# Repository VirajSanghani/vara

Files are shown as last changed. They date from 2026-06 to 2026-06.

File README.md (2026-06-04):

# VARA — a handheld perception instrument

> Point it at the world; slide on a cartridge, and it gains a new sense. The hero cartridge is
> a vision/macro lens — aim it at a plant, a part, a circuit, a label, and VARA identifies and
> explains it. The hero engineering component is the **dovetail rail connector** every cartridge
> shares, taken through a real, watchable optimization arc.

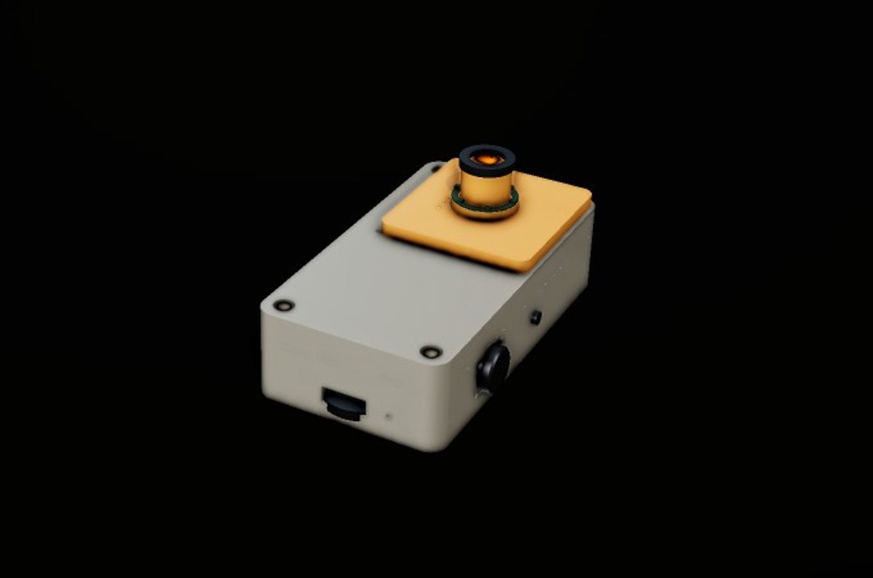
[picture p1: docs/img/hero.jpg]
VARA — assembled


*Interactive showcase (explode the device, watch the connector evolve, see the point-and-identify
loop): run `web/` locally — see [Run the showcase](#run-the-showcase-locally). Pronounced
**VAH-rah**, from Sanskrit वर — "boon, the chosen thing."*

---

## See it move

The whole assembly, every part flying from exploded to seated and back — on a loop. This is
rendered straight from the CAD: a single animated glTF (enclosure, the optimized dovetail
connector, M2.5 screws, and the representative internals) played in `<model-viewer>`.

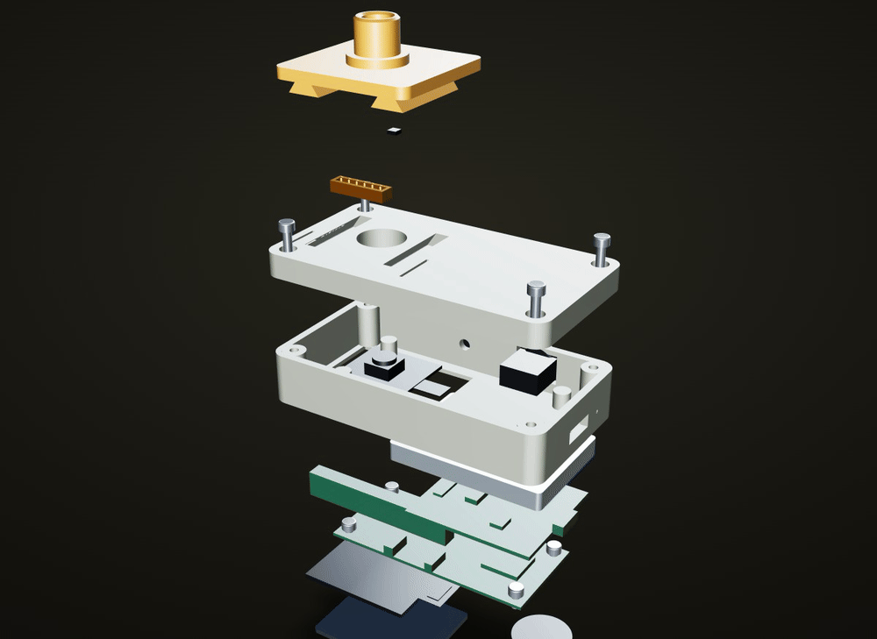
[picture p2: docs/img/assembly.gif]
VARA — the full device assembling, on a loop


Held open, the same geometry is an **annotated teardown** — every part on its own axis with a
leader label, each badged **DESIGNED** (geometry I engineered) or **REP** (a representative,
off-the-shelf stand-in I selected and modelled to size):

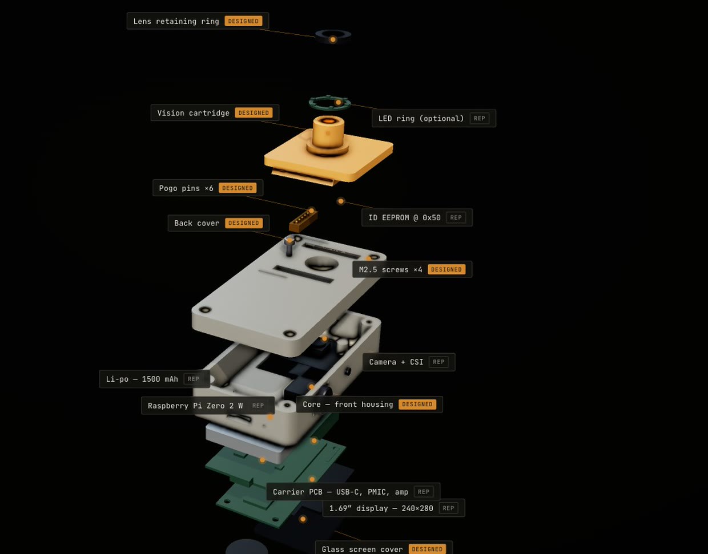
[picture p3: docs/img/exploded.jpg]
VARA — annotated exploded teardown


*Both come from the real Phase-6 part models with creased-normal shading and a studio HDR
environment. The standalone animation lives in [`web/assembly/`](web/assembly/); the annotated
teardown above is a frame from the fully interactive showcase in [`web/`](web/), where you can
drag the explode slider and tap any part for what it does **and why**.*

---

## Read this first — what VARA is, and isn't

VARA is **one complete, honest engineering pass** — hypothesis → printable enclosure + an
optimized connector → a representative integration → a working software prototype → an
interactive showcase → documentation — **not a manufactured product.**

- **No printer and no live hardware were in the loop.** Every fit, tolerance, force, and
  runtime here is **"validated-by-design," never "tested."** Where a number is analytical or an
  estimate, it says so.
- The **Raspberry Pi is the real brain**; the custom electronics are a **documented design**
  (schematic + netlist + BOM), **not a fabricated, routed, or electrically-verified board**.
- This honesty is the project's spine. For the robotics-lab role that seeded it, a credible
  end-to-end pass that's clear about its own boundaries is *more* useful than fake polish.

If you take one thing from this repo: **the record of decisions, dead ends, and tradeoffs is the
deliverable** — see [`BUILDLOG.md`](BUILDLOG.md).

---

## The story

**It starts with a capability probe, not a CAD model.** Before committing ambition, the tools
were tested ([`docs/tool-capabilities.md`](docs/tool-capabilities.md)): the FreeCAD MCP turned
out to be a dead stub, so all CAD runs on **build123d** (headless, parametric, diagnostics-first);
there's **no FEM available anywhere**, so stress is analytical and labelled as such; and **KiCad
was absent**, which set an honest ceiling for the electronics long before any schematic was drawn.

**The camera belongs in the core, not the cartridge.** A camera is a CSI-2 ribbon — far too fast
for a 6-pin pogo interface. Putting it in the core keeps the cartridge interface low-speed and
makes the hero cartridge *optics only*: a swappable macro lens over a fixed eye, like a microscope
objective. The payoff is a single constraint doing double duty — the cartridge lens must be
**coaxial** with the fixed camera, so the dovetail's **±0.28 mm** alignment budget governs the
*optical axis*, not just the electrical pads.

**The dovetail earned its place as the centerpiece** because its objectives genuinely fight:
locate precisely ↔ slide easily, lock firmly ↔ survive thousands of cycles, be stiff ↔ be
printable in PA12-CF. It was taken through **six problem-driven generations**
([`docs/dovetail-study.md`](docs/dovetail-study.md)), each fixing what the last exposed:

| Gen | What changed | Result |
|---:|---|---|
| **G1** | spec seed values | **catastrophic** — detent ε ≈ 13.5 %, ~1253 N to insert (it would shatter), alignment 0.40 mm |
| **G2** | a dedicated cantilever snap-finger | stress fixed in-plane, but fails the FDM interlayer case; alignment still off |
| **G3** | tighten clearance + declare a print-tolerance spec | alignment lands *exactly* on the 0.30 mm budget — kept as a marginal finding |
| **G4** | lower the detent depth | first **PASS** — but zero alignment margin |
| **G5** | thinner/longer finger, tighter fit | real margin — but the lock went soft (7.2 N) |
| **G6** | balance finger + detent + rail length | **resolved**: SF 5.1 / 2.56, **2.9 N** insert, **10.6 N** lock, **0.28 mm** alignment |

Beam theory understates the real stress at the finger root, so a **protected root fillet** carries
that load — and it's gated in code so a future refactor can't quietly shrink it. The marginal and
failing generations are kept, not hidden; they're how the part reasoned its way to a form.

**The electronics were designed honestly to a known ceiling.** `kicad-cli` validates and exports
but cannot place symbols, so the schematics were hand-authored as s-expressions and driven through
the CLI: openable `.kicad_sch`, an ERC-clean netlist (**0 unconnected pins**), and a BOM
([`docs/electronics.md`](docs/electronics.md)). The 6-pin contract — `V+ · GND · I²C SDA · I²C SCL
· CD# · INT` — maps exactly on both the core and the cartridge. **PCB routing was not pursued**
(the tool can't route); that limit is stated, not papered over.

**The prototype runs the real loop** ([`app/`](app/), [`docs/prototype.md`](docs/prototype.md)):
jog-press → camera capture → cloud vision identify → viewfinder + caption on the 1.69″ display →
speak. One detail is enforced *in code*: the shared V+ rail powers both the ID EEPROM and the LED
ring, and LED dimming PWMs that rail — so the firmware **must read the EEPROM ID before any PWM**.
`enable_power_pwm()` raises a `SequencingError` if it doesn't, and the demo proves the guard fires.
No Wi-Fi, no API key, or a timeout each produce a clean on-screen error — never a crash.

---

## Designed vs. representative — what I engineered, and what I selected

The line matters. **I engineered** the mechanical and interface design; I **selected** off-the-shelf
electronics and modelled them as dimensional stand-ins. This never rounds up to "designed the
electronics."

| **Designed by me** (geometry / interface / integration) | **Selected** (off-the-shelf, representative) |
|---|---|
| Dovetail connector — full optimization, male + female STLs | Raspberry Pi Zero 2 W (the compute / "brain") |
| Core enclosure (front housing + back cover), DfAM in PA12-CF | 1.69″ 240×280 ST7789 display module |
| Vision cartridge — lens barrel, LED-ring + EEPROM pockets, rails | Li-po cell, IP5306 PMIC, MAX98357A amp, USB-C |
| The 6-pin interface **contract** (pinout, EEPROM scheme, keep-outs) | Pi camera module + CSI ribbon |
| Fastener plan (M2.5 SHCS), heat-set bosses, print orientation | EC11 jog encoder, MEMS mic, speaker |
| The electronics **schematic / netlist / BOM** (a design) | — *(no routed PCB exists; not claimed)* |
| The Pi software pipeline + the read-before-PWM guard | — |

In the showcase teardown, every part carries a **DESIGNED** or **REPRESENTATIVE** badge for the
same reason.

---

## What it can do — and where it can go

VARA is a **platform**, not a single gadget. The thing that makes it one is the frozen interface
contract: a cartridge is anything that fits the dual-rail dovetail envelope and speaks the 6-pin
bus — `V+ (3V3 switched, ≤150 mA) · GND · I²C SDA · I²C SCL · CD# (detect) · INT`, with an
EEPROM ID at `0x50`. Design that contract once, and every future "sense" is just a new cartridge.

**What works today (the prototype loop, [`app/`](app/)).** Jog-press → the core camera captures →
a cloud vision model identifies → a viewfinder + caption render on the 1.69″ display → it speaks.
The core reads the cartridge's EEPROM ID on attach and can branch behaviour per cartridge. Every
failure mode (no Wi-Fi, no API key, a timeout) degrades to a clean on-screen message, never a
crash. This is **logic-validated with swappable stubs, not hardware-tested.**

**Designed-in extensibility (the contract already supports it).** Because the connector and bus
are frozen, these need *no change to the core* — only a new cartridge body + an I²C sensor:

| New "sense" | Representative sensor | Fits because |
|---|---|---|
| **Thermal / IR** | MLX90640 32×24 array | low-rate I²C, brings its own optics |
| **Air-quality / smell** | BME688 gas·VOC·T·RH·P | pure I²C, microwatts |
| **Macro / microscope** *(the hero, built)* | swappable lens over the core eye | exercises the ±0.28 mm optical-axis budget |

The honest edge case is **audio/ultrasonic**: raw streaming exceeds the low-speed 6-pin contract,
so that cartridge would need a small on-cartridge MCU to do DSP and report over I²C. That's not a
flaw — it's the contract telling you where its boundary is (see
[`docs/future-cartridges.md`](docs/future-cartridges.md); none of these are modelled).

**Where it could go next — concrete, unbuilt.** In rough order of "makes it real":

- **Close the hardware loop** — actually print the enclosure in PA12-CF, *measure* the dovetail
  fit and snap force against the analytical predictions, and **route + fabricate the PCB** (routing
  was explicitly not done; the design stops at an ERC-clean schematic/netlist/BOM).
- **Go offline / on-device** — swap the cloud vision call for a small local model on the Pi, so
  identification works with no network; keep the cloud path as an optional "deep" mode.
- **More senses** — any of the I²C cartridges above; a UV or polarised-light optic; a barcode/OCR
  reader; a depth or telephoto module (CSI-bandwidth senses live in the *core*, like the camera).
- **Smarter compute** — drop in a Pi 5 / CM4 / Jetson-class board behind the same enclosure and
  interface for heavier on-device perception, or add a follow-up voice-Q&A loop over each result.
- **Add a high-speed contract variant** — a superset connector for senses the 6-pin bus can't
  carry, without breaking the low-speed cartridges that already conform.

The spine still holds for all of it: this repo is **validated-by-design, not manufactured or
hardware-tested** — the value is a contract proven to generalise and a record of how it got there.

---

## Repo map

```
vara/
  BUILDLOG.md          phase-by-phase decision record (read this for the process)
  docs/                architecture · connector-spec · dovetail-study · mechanical ·
                       electronics · prototype · tool-capabilities · future-cartridges
  cad/                 build123d sources + ST/STEP/glTF  (connector/ core/ cartridge/ showcase/)
  electronics/         hand-authored KiCad schematics, CLI-exported netlist/BOM/PDF, ERC
  app/                 the Pi prototype (capture → vision API → display + speak); see app/README.md
  web/                 the Three.js exploded showcase (static, no build)
```

## Run the showcase locally

It's static files, no build step — just serve the folder (ES modules need http, not `file://`):

```bash
cd web && python3 serve.py 8000      # no-cache static server → http://localhost:8000
# or any static server: python3 -m http.server 8000
```

Three scenes: **Explode** (drag the slider; tap a marker for what each part does *and why*),
**Connector** (step/play the six generations with the real numbers), **Identify** (the
point-and-identify story with the real prototype frames). Drag to orbit; use the **view** presets.
Needs internet (three.js loads from the jsdelivr CDN).

There's also a **standalone auto-playing assembly animation** at **`web/assembly/`** — the full
device flying from exploded to seated, on a loop, built as an animated glTF and played in
`<model-viewer>` (a simpler, passive alternative to the interactive scene).

## Run the Pi app

See [`app/README.md`](app/README.md) for flashing a Zero 2 W and wiring. Off-device, the logic
path runs with stubs:

```bash
pip install pillow anthropic
python3 -m app.demo        # exercises init + a scan + every failure mode
```

**What's stubbed off-device:** camera, display, audio, encoder, cartridge I²C, and the vision API
are swappable stubs (each logs "STUB" at startup); the rendered display frames are real. On a Pi
with the libs + an `ANTHROPIC_API_KEY` in a gitignored `.env`, the real drivers take over. The app
is **logic-validated, not hardware-tested**.

---

## License

Mixed software + hardware, so the recommendation is a **dual license** — see [`LICENSE`](LICENSE):
**MIT** for the software (`app/`, `web/`, build scripts) and **CERN-OHL-S v2** (strongly
reciprocal) for the hardware (`cad/`, `electronics/`). MIT keeps the software trivially reusable;
CERN-OHL-S keeps hardware derivatives open. (A single permissive license is the alternative if
simplicity matters more — the tradeoff is laid out in `LICENSE`.)

## Built with

- **[build123d](https://github.com/gumyr/build123d)** 0.10 via the **forge-cad** pipeline — all parametric CAD, diagnostics, and glTF export.
- **[three.js](https://threejs.org/)** r160 (CDN-pinned) — the interactive showcase.
- **[KiCad](https://www.kicad.org/)** 10.0.3 (`kicad-cli`) — schematic validation + netlist/BOM/PDF export.
- **Raspberry Pi Zero 2 W** + the **Anthropic** vision API — the prototype brain and perception.

*A complete engineering pass, documented as an engineer would — decisions, tradeoffs, and dead ends.*

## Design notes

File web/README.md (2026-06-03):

# VARA showcase (web/)

The interactive exploded showcase — the wrapper that makes the whole build legible in ~60 s.
Static Three.js, **no build step**. It consumes the **real** project geometry and data:

- `assets/models/core.glb`, `cartridge.glb` — the Phase-3 printable parts (build123d → glTF).
- `assets/models/gen1…6.glb` — the Phase-2 dovetail evolution set.
- `assets/frames/*.png` — the Phase-5 prototype's real display renders.
- numbers in `src/data.js` come straight from `docs/dovetail-study.md` (analytical estimates).

## Three scenes
1. **Explode** — core ↔ cartridge separate; tappable markers give *what* each feature does
   **and why it's shaped that way** (rail span drove the form, the optical bore is coaxial,
   the finger-root fillet is functional, …).
2. **Connector** — step/play through the 6 generations, G1 (ε 13.5 %, 1253 N, FAIL) →
   G6 (SF 5.1, 2.9 N insert, 10.6 N retention, RESOLVED), numbers updating live.
3. **Identify** — the product story + the cartridge sliding on + the capture→identify→speak
   loop using the real Phase-5 frames.

## Run / deploy
It's plain static files — serve the folder over HTTP (ES modules need http, not `file://`):
```bash
cd web && python3 -m http.server 8000   # → http://localhost:8000
```
Deploy by uploading `web/` to any static host (GitHub Pages, Netlify, Cloudflare Pages, S3).
That URL is the single shareable link.

## Notes
- **Three.js r160 loads from the jsdelivr CDN** (pinned) via an import map — keeps the artifact
  light. For a fully offline/self-contained copy, vendor `three.module.js` + the four addons
  (`GLTFLoader`, `OrbitControls`, `CSS2DRenderer`, `RoomEnvironment`) and repoint the import map.
- **Perf:** meshes are already light (≤ ~95 KB each, no decimation needed); evolution GLBs and
  frames lazy-load on first entry to each scene; pixel ratio is capped (1.5× on mobile, 2× otherwise).
- **Graceful degradation:** a WebGL check shows a clean fallback message; layout reflows for mobile.
- **Honesty in the UI:** a persistent footer states the numbers are first-order analytical
  estimates — validated-by-design, not hardware-tested.

## Files
```
index.html        shell + import map + scene panels
src/styles.css    Quiet Utility theme (Fraunces + JetBrains Mono, stone/amber)
src/main.js       renderer, materials, the 3 scenes, lazy loading, camera moves
src/data.js       part callouts (what/why), gen metrics, story, honesty text
assets/           models/ (real glTF) · frames/ (real Phase-5 renders)
```

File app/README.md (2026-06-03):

# VARA prototype — run & flash

The functional pipeline: **jog-press → camera capture → cloud vision identify → viewfinder +
caption on the 1.69″ display → speak**. The brain is a real Raspberry Pi Zero 2 W; identify+
explain is a cloud API call (no on-device VLM — Phase 1). See `../docs/prototype.md` for what
runs vs. what's stubbed and the handled failure modes.

## Off-Pi logic demo (no hardware)
```bash
pip install pillow anthropic          # only these needed for the demo
python3 -m app.demo                   # exercises init + a scan + every failure mode
```
Renders display frames to `app/_out/` and a TTS transcript. **Logic-validated, not
hardware-tested** — camera/display/audio/cartridge/vision are stubs (logged at startup).
Sample frames are committed in `app/samples/`.

## Run on a real Raspberry Pi Zero 2 W
1. **Flash** Raspberry Pi OS (Bookworm, 64-bit Lite) with Raspberry Pi Imager; set Wi-Fi +
   SSH in the imager (Wi-Fi is required — the vision call needs network).
2. **Enable interfaces:** `sudo raspi-config` → enable **SPI** (display), **I2C** (cartridge
   EEPROM), **I2S** (audio), and the **camera**.
3. **Wire** per `../electronics/` (SPI display, I²S mic+amp, EC11 on GPIO5/6/16, USB-C PMIC,
   CSI camera, 6-pin pogo). Pin map = `../electronics/netlist.csv`.
4. **Install:**
   ```bash
   sudo apt install -y espeak-ng python3-picamera2
   pip install -r app/requirements.txt st7789 gpiozero smbus2
   cp .env.example .env && nano .env        # paste ANTHROPIC_API_KEY
   ```
5. **Run:** `python3 -m app.main`  (jog press = scan, long-press = shutdown).
   For boot-on-power, wrap in a `systemd` service.

Missing any Pi library → that subsystem auto-falls-back to its **stub** (logged), so the app
still starts. No `ANTHROPIC_API_KEY` → degraded mode showing a clean "No API key" screen.

## Layout
```
app/
  config.py      .env load + REAL/STUB selection (logged)
  state.py       pipeline states + typed vision errors
  vision.py      cloud client (RealVisionClient + StubVisionClient)
  pipeline.py    cartridge init (ID→PWM) + scan loop + degradation
  main.py        real-device entry           demo.py  off-Pi logic demo
  hal/           camera · display · audio · control · cartridge  (interface + real + stub)
```

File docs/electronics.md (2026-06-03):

# VARA — Electronics Design (Phase 4)

**Date:** 2026-06-03 · Artifacts: `electronics/netlist.csv`, `electronics/bom.csv`,
(stretch) `electronics/vara.kicad_*`. Tied to `connector-spec.md` **v0.2** (6-pin pogo).

> ## ⚠️ Honesty banner — read first
> **This is a DESIGN — schematic + footprints + BOM — NOT a DRC-clean, manufactured, or
> electrically-verified board.** No SPICE, no signal-integrity, no power-rail validation, no
> hardware. **No fake netlists:** every net in `netlist.csv` traces either to the frozen
> connector contract (the 6 pogo pins) or to a named component pin from `bom.csv`. Pin
> numbers for the Pi header are the physical 40-pin positions; verify against the chosen
> module before fab. Treat all of this as "validated-by-design," never tested.

---

## 1. Tooling ceiling (Phase 0 discipline, re-probed for Phase 4)
See the **Phase 4 addendum in `tool-capabilities.md`** for the empirical re-probe. Summary:
KiCad **10.0.3** installed (cask fetch + manual app extraction — full cask needs sudo);
`kicad-cli` **validates/exports but cannot place symbols**, so schematics are hand-authored
as `.kicad_sch` then driven through the CLI.

**Both floor and stretch are delivered:**
- **Floor:** `electronics/netlist.csv`, `electronics/bom.csv`, block diagram (§2), contract
  mapping (§3).
- **Stretch (verified working):** openable, ERC-checked `vara_core.kicad_sch` +
  `vara_cartridge.kicad_sch` (generated by `gen_kicad_sch.py`), with CLI-exported
  **netlist** (`*.net`), **BOM** (`*.bom.csv`), and **PDF** (`*.pdf`).
  - **Connectivity proven by the exported netlist:** core = **29 nets, 0 unconnected pins**;
    cartridge = **6 nets, 0 unconnected pins**. The 6 contract nets map exactly (§3).
  - **ERC:** no electrical errors; only cosmetic warnings remain — `lib_symbol_issues` /
    `footprint_link_issues` (the custom symbol lib and footprints aren't registered in a
    project library table; symbols are embedded so the files open, footprints are referenced
    by name for the BOM). No dangling labels, no unconnected pins.
- **PCB layout NOT pursued:** `kicad-cli pcb` cannot place/route; per the brief, routing is
  optional dessert. We stop at schematic + netlist + BOM + PDF depth.

---

## 2. System block diagram

```mermaid
graph LR
  USBC[USB-C J1] -->|VBUS 5V| PMIC[IP5306 PMIC U2]
  BATT[Li-po 1500mAh BT1] <-->|charge / boost| PMIC
  PMIC -->|+5V| PI[Pi Zero 2 W A1]
  PMIC -->|+5V| AMP[MAX98357A U4]
  PMIC -->|+5V| LDO[AP2112 3V3 U6]
  LDO -->|+3V3_SYS| DISP[1.69 ST7789 DS1]
  LDO -->|+3V3_SYS| MIC[SPH0645 MK1]
  LDO -->|+3V3_SYS| LSW[Load switch U5]
  PI -->|SPI0 + DC/RST/BLK| DISP
  PI <-->|I2S BCLK/LRCLK| MIC
  PI -->|I2S DOUT| AMP
  MIC -->|I2S DIN| PI
  AMP -->|BTL| SPK[Speaker LS1]
  PI <-->|A/B/SW| ENC[Encoder SW1]
  ENC -->|long-press| PMIC
  PI -->|CSI-2 FFC| CAM[Camera CAM1]
  PI -->|GPIO26 EN/PWM| LSW
  LSW -->|V+ switched 3V3| J2
  PI <-->|I2C1 SDA/SCL| J2
  PI <-->|CD#, INT| J2
  J2[[6-pin pogo J2]] ===|pogo| PADS[Cartridge pads]
  PADS --> EE[EEPROM 0x50 U3]
  PADS --> LED[LED ring D1-6]
  PADS --> SHUT[Shutter SW2 -> INT]
```

---

## 3. The cartridge interface — netlist tied EXACTLY to `connector-spec.md` v0.2
The contract is 6 pins. Every one maps to a real net on both sides:

| Pin | Contract net | CORE side (net / node) | CARTRIDGE side (net / node) |
|----:|---|---|---|
| 1 | **V+ (3V3 switched)** | `V+_SW` ← U5.VOUT (load switch, ≤150 mA, EN=GPIO26) | `CV+` → U3.VCC + LED-ring anodes |
| 2 | **GND** | `GND` (J2.2) | `CGND` → U3.GND/A0/A1/A2/WP, LED return, SW2 |
| 3 | **I²C SDA** | `I2C_SDA` ← GPIO2, pull-up R1 4.7k→3V3 | `CSDA` → U3.SDA |
| 4 | **I²C SCL** | `I2C_SCL` ← GPIO3, pull-up R2 4.7k→3V3 | `CSCL` → U3.SCL |
| 5 | **CD# (detect)** | `CART_CD` ← GPIO23, pull-up R3 10k→3V3 | `CCD` = **hard-tied to GND** (presence) |
| 6 | **INT** | `CART_INT` ← GPIO12, pull-up R4 10k→3V3 | `CINT` ← SW2 shutter (to GND when pressed) |

**Mate/power sequence (firmware, per connector-spec §4.2):** CD# falls (seated) → Pi enables
`CART_VEN` (V+ load switch on) → settle → read EEPROM @0x50 → configure pipeline → arm INT.

---

## 4. Subsystem notes & deliberate design decisions
- **Power chain:** IP5306 does charge + 5 V boost + power-path + button + fuel gauge in one
  chip (board-area win). Pi runs from +5 V and uses its own internal regulators. A separate
  **AP2112 3V3 LDO (U6)** derives `+3V3_SYS` for peripherals **and** the switched cartridge
  rail — deliberately **not** tapping the Pi's weak 3V3 header pin, which couldn't source the
  cartridge's ≤150 mA.
- **Switched cartridge rail (U5):** a current-limited load switch gates V+ so (a) a fault on a
  cartridge can't brown out the core, and (b) V+ is off until the core has identified the
  cartridge. `R5` 100k holds it off at boot.
- **LED-ring dimming without a 7th pin:** there is no dedicated PWM line in the 6-pin
  contract, so the **core PWMs the V+ load switch (GPIO26)** to dim the ring. The EEPROM is
  read **once at insertion while V+ is steady**, *before* any PWM — so power-cycling the rail
  for dimming doesn't disturb ID. Documented tradeoff, not a hidden hack.
- **Audio:** I²S mic (SPH0645) and amp (MAX98357A) share BCLK/LRCLK; mic on PCM_DIN, amp on
  PCM_DOUT — standard full-duplex I²S.
- **Camera:** Pi camera connects by the **CSI-2 FFC ribbon to the Pi's camera port (J3),
  NOT through the pogo pins** — CSI is far too high-bandwidth for the 6-pin low-speed contract
  (this is *why* the camera lives in the core; see architecture.md §2).
- **Single control:** the EC11 encoder's A/B/SW go to the Pi for UI.

## 5. Known integration risks (named, per honesty rules)
1. **Shared button (`ENC_SW` = `PWR_KEY`):** the encoder push drives both a Pi GPIO (UI) and
   the IP5306 KEY (power). IP5306's long-press/double-click power behaviour can collide with
   UI gestures. **Mitigation option** if it proves annoying: a separate dedicated power
   tactile on KEY, freeing the encoder for UI only. Flagged for bench resolution.
2. **Pi header pin numbers** are the physical positions for a standard 40-pin Zero 2 W; the
   chosen GPIO↔function map (SPI0, I²C1, I²S, the GPIO assignments) must be confirmed against
   the device-tree overlay before fab.
3. **Current budget:** the ≤150 mA cartridge rail assumes a modest LED ring (6× ~20 mA with
   R6 limiting). A brighter ring needs a rethink of U5 / rail sizing.
4. **No power-integrity / EMC / thermal analysis** has been done.

## 6. What is explicitly NOT claimed
No DRC pass, no routed-and-poured copper claimed as verified, no impedance control, no
manufactured board, no electrical bring-up. The deliverable is a **coherent, contract-tied
design** an engineer could take to layout — and the stretch artifacts (if the probe allows)
are an **openable KiCad project**, still a design, not a verified board.

## 7. Outputs
**Floor:**
- `electronics/netlist.csv` — every net, every node, tied to the connector contract or a BOM pin.
- `electronics/bom.csv` — full BOM with part numbers, packages + subsystems.

**Stretch (openable KiCad project + CLI exports):**
- `electronics/vara_core.kicad_sch`, `electronics/vara_cartridge.kicad_sch` — hand-authored,
  ERC-clean (cosmetic warnings only). Open in KiCad 10.
- `electronics/gen_kicad_sch.py` — the generator (single source: components + per-pin nets).
- `electronics/vara_core.net`, `vara_cartridge.net` — CLI-exported netlists (connectivity proof).
- `electronics/vara_core.bom.csv`, `vara_cartridge.bom.csv` — CLI-exported BOMs.
- `electronics/vara_core.pdf`, `vara_cartridge.pdf` — rendered schematics.
- `electronics/*.erc.rpt` — ERC reports. `electronics/*.kicad_pro` — project files.

> Reproduce: `python3 electronics/gen_kicad_sch.py` then
> `kicad-cli sch {erc,export netlist,export bom,export pdf} electronics/vara_core.kicad_sch`.

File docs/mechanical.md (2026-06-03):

# VARA — Mechanical Design & Design-for-AM (Phase 3)

**Date:** 2026-06-03 · Parts: **core body** + **hero vision cartridge**, both consuming the
**resolved Gen-6 connector geometry** (`connector-spec.md` v0.2) via `dovetail_lib`
primitives — the `[STUDY]` geometry was **not re-opened**. Source:
`cad/core/core_body.py`, `cad/cartridge/vision_cartridge.py`, `cad/vara_assembly.py`.

> **Honesty banner:** No printer is in the loop — every fit/orientation is
> **"validated-by-design, print-ready," never tested.** Material is **PA12-CF** (FDM).
> Internal packaging (Pi, battery, PMIC) is dimensionally representative, not a routed
> layout. The core is modeled as a **sealed unibody** for a clean watertight single-STL
> deliverable; the production part splits on a rear parting line (see §6).

---

## 1. What was built (and the gate results)

| Part | bbox (mm) | mass (PA12-CF) | solids | watertight | gates |
|---|---|---|---|---|---|
| Core body | 44 × 64 × 20 | 21.9 g | 1 | **yes** | **5/5** |
| Vision cartridge | 26 × 35.6 × 19 | 5.9 g | 1 | **yes** | **5/5** |
| Assembly (semi-exploded) | 44 × 64 × 43 | — | 2 | yes | **0 interferences** |

**Geometry gates run (forge `REQUIREMENTS`, on the real solids):**
- Core: valid+watertight · optical bore Ø13 clear path · pad strip flat (nothing past the
  mating plane) · rail socket actually formed · **protected finger-root fillet ≥ 0.5 mm**.
- Cartridge: valid · barrel bore (optical path) clear end-to-end · pad strip exposed below
  the mating plane · within 32×36×26 envelope · rails+barrel **fused to one solid**.

**Device proportions — honest consequence of the connector.** The rail span (35.6 mm in Y)
plus the 1.69″ display set the core at 44 W × 64 H × 20 T mm: a chunky, grippable instrument,
not a thin phone. That thickness/height is *driven by the frozen connector geometry* and the
need to seat the camera coaxially behind the cartridge — stated plainly rather than fought.

---

## 2. Core body — feature inventory
Display: 1.69″ 240×280 bezel recess (module 30.4×36.6, +0.4 clearance) with a through window
to the **28.0 × 32.6 mm active area** (viewfinder + caption split is software on one panel).
Back: integrated **female rail socket** (Gen-6, with the snap-finger slots + detents) and the
**Ø14 optical bore** coaxial with the cartridge barrel, behind it a camera mount pocket.
Sides/edges: **USB-C** cutout (bottom), **jog-encoder** aperture (right edge), **I²S mic**
port (bottom), **speaker grille** (3×3, front lower). Internal: sealed electronics cavity +
**4× M2.5 heat-set bosses** on the Pi Zero 2 W hole pattern (58 × 23 mm).

## 3. Vision cartridge — feature inventory
**Male rails** (Gen-6, consumed as-is, with seating dimples) → backing plate (3 mm) →
**macro-lens barrel** coaxial on the optical axis (Ø12 outer, **Ø8 bore = optical path**,
12 mm tall). **LED-ring recess** (Ø16/Ø12.5, 2 mm) around the barrel base facing the subject.
**EEPROM-ID pocket** (5×4×1.6 mm) on the underside near the pad strip. **6 flat pogo-pad
seats** (Ø2.0, 2.54 mm pitch, 0.3 mm recess) on the underside at X=6. Optical coaxiality of
the barrel is governed by the connector's **±0.28 mm** alignment budget.

---

## 4. Design-for-AM — per part

### Print orientation (the real tension, resolved per part)
There is **no single orientation optimal for every face**; each part is oriented for *its*
most critical faces, and the connector's alignment margin (0.28 < 0.30 mm) + the finger-root
fillet absorb the residual.

- **Core body → front-face-down.** Screen face flat on the bed (best cosmetic face); the
  back socket + bosses build upward. Two payoffs: (1) the female groove flanks sit at ~35°
  from vertical — **within the FDM ~45° self-support limit, no support in the sliding zone**;
  (2) layers stack along the device thickness (conn-Z), so the **snap finger flexes
  *in-plane*** → the **in-plane SF_yield ≈ 5.1 applies, not the interlayer case** (better than
  the Phase-2 worst-case assumption). Bosses' heat-set bores open upward (toward the print
  top), clean to ream.
- **Vision cartridge → rail-axis (X) vertical** (stand on the +X mouth end), per the Phase-2
  connector resolution. Rail flanks become near-vertical walls → **support-free sliding
  faces** (the alignment-critical surfaces win). Trade-offs, stated: the **barrel bore prints
  horizontally** (top crown slightly rough → **ream the Ø8 bore**, standard for an optical
  barrel); the **pad face prints vertical** → the flat gold pads are an adhered contact strip
  that seats into the 0.3 mm recess, so layer texture under them is non-critical.
  *(Rejected alternative: rail-floor-down — leaves a 26 mm unsupported plate-underside bridge
  across the central pad/optical channel, which would need support exactly on functional
  faces. Rejected.)*

### Wall thickness, clearances, supports, fasteners

| Item | Core | Cartridge |
|---|---|---|
| Wall thickness | 2.4 mm side / **3.0 mm front (screen)** (≈6–7 perimeters @0.4 mm) | 3.0 mm plate / **2.0 mm barrel** |
| Connector walls | female `wall_thk` 2.4, finger 1.1 (from study, unchanged) | rails per study |
| Support on functional faces | **none** (front-down → flanks self-support; finger in-plane) | **none on flanks** (rail-vertical); bore reamed |
| Fasteners / heat-set | **4× M2.5 heat-set** (Pi mount); melt bore Ø3.4 (Ø2.2 pilot shown) + rear-cover corner inserts (production) | **none** — snap-fit retention; LED ring / EEPROM / lens retained by pockets + adhesive |

### Tolerance call-outs
| Feature | Nominal | Tolerance / clearance |
|---|---|---|
| Dovetail flank fit | `flank_clearance` 0.13 mm | **per-part print tol ≤ ±0.075 mm** (calibrated printer) — required to hold ±0.30 mm budget (study §4) |
| Display module pocket | 30.4 × 36.6 mm | +0.4 mm |
| Optical bore | Ø14 (lens Ø12) | +0.0/−0.0 keep-out; lens clear aperture ≤ Ø12 |
| Pad pattern | 2.54 mm pitch, Ø2.0 | recess 0.3 mm; pads = adhered contact strip |
| USB-C cutout | 9.2 × 3.6 mm | +0.4 mm over connector body |
| Heat-set boss bore | Ø3.4 (M2.5) | per insert datasheet |

---

## 5. Keep-outs — validated by gate (not by eye)
- **Optical bore:** a Ø13 test cylinder through the core back is empty (< 5 mm³); the
  cartridge barrel **bore** is open end-to-end — the optical path is clear and coaxial. ✔
- **Pad strip:** nothing on either part protrudes past the mating plane into the X=6 pad
  footprint → pads stay flat for pogo contact. ✔
- **Central channel:** rails are outboard at Y=±13 (inner edge ≥ 7.0 mm by the connector
  gate), so pads (Y±6.35) and the Ø14 bore stay clear. ✔
- **Envelope:** cartridge 26×35.6×19 ≤ 32×36×26. ✔ (Y=35.6 is tight against the 36 mm limit
  — flagged; any future wider rail would breach it.)

## 6. Production note (why the core is a sealed unibody here)
A printed enclosure is two shells. The single watertight STL seals the electronics cavity
for a clean manifold deliverable; the **production core splits on a rear parting line** into
the front housing (shown) + a back cover, joined at the **4× M2.5 heat-set bosses** (on the
real Pi hole pattern). The cavity dimensions and boss pattern are the real internal layout;
only the closing face is sealed in this STL. The cartridge needs no such split (snap-fit).

## 7. Protected feature — finger-root fillet
The detent **finger-root fillet (0.6 mm)** is a **functional** feature: the straight-beam
stress model (study §2) understates the real stress concentration at the finger root, so the
fillet is what keeps the actual peak stress in check. It is gated (`finger_root_fillet ≥ 0.5`)
and **must not be reduced for packaging convenience**, per the Phase-3 brief.

## 8. Outputs & honest limitations
**Outputs:** `cad/core/core_body_v1.{stl,step}`, `cad/cartridge/vision_cartridge_v1.{stl,step}`,
`cad/vara_assembly_v1.glb`, per-part diagnostics in `cad/*/out/`.
**Limitations:** (1) internal packaging is representative, not routed — Pi/battery/PMIC fit is
asserted by envelope, not by a populated layout; (2) the sealed-unibody core defers the real
parting-line/cover detailing; (3) no fit, insertion, or drop behaviour is measured —
validated-by-design only.

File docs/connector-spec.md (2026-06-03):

# VARA Cartridge Interface — CONTRACT SPEC v0.2

**Date:** 2026-06-03 · **Status:** contract frozen for Phase 2/3; dovetail *profile* is a
Phase-2 study variable (clearly tagged below). **This document is the single source of
truth.** Every core and cartridge part references it. Change a value here → propagate
everywhere downstream (architecture, CAD, electronics). Bump the version on any change.

> Two kinds of numbers live here. **[CONTRACT]** = frozen; any cartridge ever built must
> conform, and the core mates to it. **[STUDY]** = the dovetail cross-section geometry being
> optimized in Phase 2; the current best always lives in `cad/connector/`. The contract is
> stable even while the profile evolves — that separation is deliberate.

---

## 1. Coordinate datum & reference frame [CONTRACT]

A single right-handed frame governs both halves. The **female** rail is in the **core**;
the **male** rail is on the **cartridge**.

```
            +Z  (out of core mating face; OPTICAL AXIS ∥ +Z; cartridge sits above)
             │           camera (in core) looks out +Z through cartridge barrel
             │
             │     ┌───────────── cartridge envelope ──────────────┐
             │     │   ◎ optical axis @ (Xopt,0)   ⦿ LED ring      │
             O─────┼────●●●●●● pad array @ (Xpad, Y)────────────────┼──▶ +X
          (datum   │                                                │   (removal dir;
           origin) └────────────────────────────────────────────────┘   insertion = −X)
             │      ◀── slides −X to seat against stop at X=0 ──
            +Y (lateral, into page complete RH frame)
```

- **Origin O** = center of the **positive-stop face**, on the rail axis, at the mating
  base plane. All features are dimensioned from O.
- **+X** = cartridge **removal** direction. Insertion travels **−X** until the male rail's
  seat face contacts the stop at **X = 0** (hard positive stop — cartridge cannot
  over-insert).
- **+Z** = normal to the core mating base plane, pointing toward the cartridge. The core
  camera looks out **+Z**; the cartridge lens barrel is coaxial above it.
- **+Y** = lateral, completing the right-hand frame.

---

## 2. Envelope [CONTRACT]

| Item | Value | Note |
|---|---|---|
| Max cartridge bounding box (W×L×H = Y×X×Z) | **36 × 32 × 26 mm** | hard ceiling; hero cartridge sits inside this |
| Mating base plane | Z = 0 | shared face between core and cartridge |
| Insertion direction | −X | seats against stop at X=0 |
| Rail nominal length (along X) | **24 mm** [STUDY] | bearing length; affects angular stiffness |

---

## 3. Pad array & optical axis (the alignment-critical features) [CONTRACT]

Pogo pins live in the **core** (protrude +Z); flat gold pads on the **cartridge** (on the
Z=0 plane, facing −Z toward the core).

| Feature | Location (from O) | Spec |
|---|---|---|
| Pad array center | X = **+6.0 mm**, Y = 0, Z = 0 | engages only near full seat |
| Pad pitch / count | **2.54 mm × 6** | pins along Y; outer pads at Y = ±6.35 mm |
| Pad size | **Ø2.0 mm gold** | ≥ pogo crown + 2×(0.3 mm budget) + margin |
| Pogo working compression | **0.5 mm** | sets the alignment budget below |
| **Optical axis** | X = **+15.0 mm**, Y = 0, along +Z | core camera ↔ cartridge barrel, coaxial |
| Optical clear bore (keep-out) | **Ø14 mm** about the optical axis, full Z | no structure intrudes (lens clear aperture ~Ø12 + margin) |
| Pad keep-out | pad rect + 1.0 mm margin, +Z to pogo housing | no ribs/walls in the contact volume |

### 3.1 Alignment budget [CONTRACT] — the number the dovetail must hold
The pogo compression (0.5 mm) and pad oversize give an absorbable misalignment of
**±0.3 mm** at the **pad plane** *and* at the **optical axis**, in Y and X.

This budget is **lateral + angular combined**. Angular slop is the dominant risk because
the optical axis (X=+15) is **9 mm forward of the pad centroid (X=+6)**, so rail tilt is
amplified by lever arm:

```
   error_at_optical_axis ≈ lateral_play + θ · (distance from rail-bearing centroid)
   require: error_at_optical_axis ≤ 0.3 mm  AND  error_at_pads ≤ 0.3 mm
```

→ **Phase-2 acceptance:** the chosen `flank_clearance` + rail bearing length must keep
both the pad-plane and optical-axis error ≤ 0.3 mm under worst-case clearance + a stated
print-tolerance allowance. This is the dovetail study's primary quantitative gate.

---

## 4. Electrical pinout — FINAL [CONTRACT]

Pin order along Y, from −Y outer pad (pin 1) to +Y outer pad (pin 6):

| Pin | Net | Direction / level | Notes |
|----:|-----|---|---|
| 1 | **V+ (3V3, switched)** | core→cart | Core-side **load switch + current limit, ≤150 mA budget**. Enabled by firmware *after* CD# asserts. Single logic+LED rail keeps the interface to 6 pins. |
| 2 | **GND** | — | Reference. (Provision: a longer GND pogo could make-first for hot-plug safety; design-time option, not testable without hardware.) |
| 3 | **I²C SDA** | bi | Pull-up **on core**. EEPROM + any future cartridge I²C sensor. |
| 4 | **I²C SCL** | core→cart | Pull-up **on core**. 100/400 kHz. |
| 5 | **CD# (cartridge-detect)** | cart→core | Cartridge **ties to GND**; core pulls up. Falling edge = seated → core enables V+ → reads EEPROM. Replaces the seed's resistor/1-Wire ID (Zero 2 W has no ADC, so a resistor divider would need an extra ADC chip — rejected). |
| 6 | **INT** | cart→core | Active-low, core pull-up. Cartridge interrupt (e.g. shutter button, sensor data-ready). |

### 4.1 Cartridge ID — EEPROM scheme [CONTRACT]
- I²C EEPROM (24AA02-class), fixed address **0x50**.
- Layout (starting): `magic(2) | cartridge_type(1) | hw_rev(1) | serial(4) | name[16] |
  calibration/params(rest)`. The core auto-detects which cartridge is mounted and adapts
  the UI/pipeline.
- Cheapest possible cartridge still carries this EEPROM (~$0.10) — cleaner and more
  capable than a resistor code, and it reuses pins 3/4 (no extra pin).

### 4.2 Mate/power sequence (firmware, not mechanical staggering)
Pads are coplanar and pogos equal-length → all contacts close together at full seat.
Sequencing is handled in firmware: detect **CD# low** → enable **V+ load switch** →
settle → read **EEPROM @0x50** → configure pipeline → arm **INT**. This avoids needing
mechanically staggered pin lengths (which we can't validate without hardware).

---

## 5. Dovetail profile — Phase-2 STUDY SEED [STUDY]

These define the *cross-section* being optimized. **Not** part of the frozen contract —
the current best geometry always lives in `cad/connector/` and feeds Part IV's study.
**Resolved in Phase 2 — see [`dovetail-study.md`](dovetail-study.md) for the 6-generation
derivation.** Configuration: **dual rails at Y = ±13 mm** flanking the central pad/optical
channel (a single central rail would collide with the pads + optical bore).

| Param | Seed | **Resolved (Gen 6)** | Meaning |
|---|---|---|---|
| `dovetail_angle` | 55° | **55°** | Flank angle from base plane (Z=0). 90° = vertical; <90° = undercut. 55° ⇒ 35°-from-vertical flanks — self-supporting when printed rail-axis-vertical (see §6). |
| `flank_clearance` | 0.20 mm | **0.13 mm** | per-side gap. Tightened to hold the ±0.3 mm budget with margin (E_align = 0.28 mm). |
| `detent_depth` | 0.6 mm | **0.50 mm** | snap engagement; balances retention (~10.6 N) vs. finger strain. |
| `rail_length` | 24 mm | **26 mm** | bearing length; keeps pads (X=6) & optical (X=15) well inside the span. |
| `wall_thk` | 2.4 mm | **2.4 mm** | female wall (≈6 perimeters @0.4 mm nozzle). |
| `lead_in_chamfer` | 1.0 mm | **1.2 mm** | +X mouth lead-in. |
| detent | X ≈ +2.5 mm | **cantilever finger 13×1.1 mm, one per rail** | Gen 1's wall-flex detent over-strained ~5×; replaced by dedicated snap fingers. |
| (print req) | — | **rail-axis-vertical; per-part tol ≤ ±0.075 mm** | required to meet alignment + keep flanks support-free. |

**Resolved performance (analytical, validated-by-design — NOT tested):** alignment
**0.28 mm ≤ 0.30**; detent **SF_yield 5.1 / SF_interlayer 2.56**; insertion **~2.9 N**,
retention **~10.6 N**; all geometry gates 6/6, watertight.

**Objectives in tension (per plan §4.2):** stiffness↔printability ·
retention force↔insertion ease · tight fit (alignment)↔wear life · wall thickness↔size.

---

## 6. Material & print intent [CONTRACT-level intent; details Phase 3]

- **Material:** PA12-CF, FDM. No printer in the loop → all fits are
  **"validated-by-design, print-ready," never tested.**
- **The core printability↔strength tension (to resolve in Phase 2):**
  - *Rail axis vertical (X ∥ Z-build):* sliding flank faces become near-vertical walls →
    clean surfaces, **no support on functional faces**. But layer lines run ⟂ to insertion
    and the **detent cantilever loads across layers** (weak interlayer adhesion in CF).
  - *Flat on bed (X horizontal):* strong, isotropic-ish detent; but the undercut flanks
    (35° overhang at 55°) become **overhangs needing support → wrecks the sliding faces.**
  - Phase 2 resolves this with geometry (e.g. raising `dovetail_angle` toward printable
    overhang limits) + orientation, logged as generations.

---

## 7. Keep-out summary (for body integration, Phase 3)

| Zone | Keep-out |
|---|---|
| Optical bore | Ø14 mm cylinder about (X=+15, Y=0), full Z, both halves |
| Pad/pogo volume | pad rect +1 mm margin, +Z to pogo housing height |
| Detent travel | clear path for the male rail X = 0 → +24 mm during insertion |
| LED ring | annulus around optical bore, within cartridge envelope; powered from V+ (≤150 mA) |

---

## Change log
- **v0.2** (2026-06-03): Phase 2 resolved the [STUDY] dovetail profile (§5) — dual rails,
  cantilever snap fingers, c=0.13, rail_length=26, etc. **[CONTRACT] sections unchanged.**
  See `dovetail-study.md`.
- **v0.1** (2026-06-03): initial contract. Camera in core; optics-only hero cartridge;
  6-pin pogo (V+/GND/SDA/SCL/CD#/INT); EEPROM ID @0x50; ±0.3 mm alignment budget serving
  pads *and* optical axis; dovetail profile seeded for Phase 2.

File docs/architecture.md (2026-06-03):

# VARA — System Architecture (Phase 1)

**Date:** 2026-06-03 · **Status:** subsystem choices locked for Phase 2/3 entry.
This document fixes the *system* decisions. The *interface contract* (envelope, datum,
pinout, keep-outs) lives in [`connector-spec.md`](connector-spec.md) — the single source
of truth every part references.

> Honesty note: every current-draw, runtime, and fit number here is a **documented
> estimate** marked *(est.)* or *(guess)*. Nothing is bench-measured — we have no
> hardware or printer in the loop. No fit is "tested," only "validated-by-design."

---

## 1. Subsystem decisions (locked)

| Subsystem | Decision | Key reasoning / tradeoff |
|---|---|---|
| **Compute** | **Raspberry Pi Zero 2 W** | Smallest Pi with WiFi + enough OS to drive camera/SPI/audio. On-device VLM inference is impossible on *any* Pi (see §3), so compute choice is about UX smoothness, not inference — which removes the headroom argument for Pi 4/5 and favors size. |
| **Display** | **1.69" IPS, 240×280, ST7789V-class, SPI** | Taller-than-square aspect splits naturally into **camera viewfinder (top) + result/caption strip (bottom)** — the point-and-identify UX. 1.54" 240×240 kept as drop-in fallback if module sourcing/space forces it. Front-face geometry anchors to this active area (§ connector-spec keep-outs). |
| **Camera** | **In the CORE**, fixed, CSI ribbon to Pi | CSI is high-bandwidth FPC — *cannot* route through 6 low-speed pogo pins. Core holds the eye; the hero cartridge holds **optics only** (macro-lens barrel + LED ring + ID). See §2 — this is the resolved camera decision. |
| **Power** | Single Li-po + **integrated PMIC (IP5306-class)**, USB-C charge | IP5306 gives charge + 5V boost + power-path + button-control + fuel-gauge in one chip — far less board area than MCP73831 + separate boost. Alternative (MCP73831 charger + TPS61023 boost + load switch) documented if we want finer control. |
| **Battery** | **1500 mAh Li-po** (up from 1000–1200 seed) | Runtime math (§4) put 1200 mAh at ~2.9 h active; 1500 mAh buys ~3.5 h *(est.)* for little extra volume. Single cell, 3.7 V nominal. |
| **Audio** | I²S MEMS mic (e.g. SPH0645) + I²S DAC/amp (e.g. MAX98357A) → small speaker | I²S keeps it digital and clean; MAX98357A is a single-chip mono Class-D, tiny. The AI talks; you talk to it. |
| **Control** | One rotary encoder (jog) + push (EC11-class), no other buttons | R1-grade restraint per plan. Long-press = power off via PMIC button line. Scroll = navigate; press = capture/confirm. |
| **Connectivity** | Onboard WiFi (Zero 2 W) | Required — the vision pipeline is a cloud API call (§3). No WiFi = no identify. Stated as a hard dependency. |

---

## 2. The camera-location decision (RESOLVED)

**Question (flagged in the seed):** does the vision cartridge route a camera ribbon
through the dovetail, or does the core hold the camera and the cartridge hold only optics?

**Decision: the CORE holds the camera + CSI. The hero cartridge holds the macro-lens
barrel, optional LED ring, and the ID EEPROM.**

Reasoning:
- **Bandwidth.** Pi camera = CSI-2 over a 15/22-pin FPC ribbon. Forcing that through the
  6-pin pogo interface is impossible; adding a *second* high-density board-to-board
  connector at the dovetail would be fragile, expensive, and would force every cartridge
  to carry that connector. Rejected.
- **Architecture generalizes better.** With the camera in the core, the 6-pin interface
  stays low-bandwidth (power + I²C + detect + interrupt). Other (architectural-only)
  cartridges — thermal MLX90640, air-quality BME688, audio — are all **I²C/low-speed
  sensors that live in the cartridge** and speak over exactly these pins. The vision
  cartridge is the *special* case that reuses the core eye through **swappable optics**,
  exactly like a microscope with interchangeable objectives. That's a coherent instrument
  story, not a compromise.
- **Bonus constraint that earns Phase 2 its keep:** because the cartridge lens barrel
  must sit **optically coaxial** with the fixed core camera, the dovetail's alignment
  budget (±0.3 mm at the mating plane, set by pogo compression) now governs the **optical
  axis** *and* the electrical pads simultaneously. One tolerance, two functions — this is
  a real, honest multi-objective constraint for the dovetail study.

**Consequence for the spec:** `connector-spec.md` defines an **optical axis** location and
its keep-out, in addition to the pad array. The core camera looks out **+Z** (normal to
the mating base plane); the cartridge barrel is coaxial above it.

---

## 3. On-device inference vs. cloud API (documented tradeoff)

**The hero interaction — "point → identify → explain" — is a Vision-Language-Model task.
It runs as a cloud API call (Claude vision-class), not on-device.**

- **Why not on-device:** Zero 2 W = quad A53 @ 1 GHz, 512 MB RAM. A small detector
  (MobileNet-SSD / YOLO-nano) might manage ~1–5 fps of "is there an object / where,"
  but *identifying a plant species and explaining it* needs a large VLM that does not fit
  or run usefully on the Pi. **Critically, this is true of Pi 4/5 as well** — none of them
  run a good VLM locally — so the API decision is independent of Pi model and does not
  argue for the bigger Pi.
- **Pipeline:** capture frame (CSI) → optional lightweight on-device framing/region hint
  → POST image to vision API → receive identification + explanation text → TTS to speaker
  + render caption on the 240×280 strip.
- **Tradeoffs (stated plainly):**
  - ✅ Capability and answer quality far beyond anything on-device.
  - ⚠️ Latency ~1–3 s per query *(est.)*; needs WiFi; not usable offline; recurring API
    cost; an API key that **must live in `.env`, never committed** (Risk table).
- **Honesty:** the prototype (Phase 5) will make a *real* API call against a real image.
  We will not stub the model with canned answers.

---

## 4. Power budget & runtime (estimates — not measured)

Assumptions *(guess/est., to refine against datasheets in Phase 4)*:

| Mode | Draw @ system | Note |
|---|---|---|
| Idle (Pi up, WiFi assoc, screen dim) | ~0.7 W *(est.)* | Zero 2 W floor is ~0.4–0.6 W |
| Active browse (screen on, encoder use) | ~1.2 W *(est.)* | + backlight ~0.15 W |
| Query burst (WiFi TX + CPU + capture) | ~2.5 W for 1–3 s *(est.)* | intermittent |
| Audio playback | +~0.2 W avg *(est.)* | MAX98357A into small speaker |

- Blended "instrument use" average ≈ **1.3 W** *(est.)*.
- Battery: 1500 mAh × 3.7 V = **5.55 Wh**; boost ≈ 85% → **~4.7 Wh usable** *(est.)*.
- **Runtime ≈ 4.7 / 1.3 ≈ 3.5 h continuous active use** *(est.)*.
- Zero 2 W does not deep-sleep well → between sessions, **hard-off via PMIC button**
  (encoder long-press). Don't promise multi-day standby.

---

## 5. Data/signal map (core ↔ cartridge boundary)

```
        CORE                                          CARTRIDGE (hero: vision optics)
  ┌─────────────────────────┐                    ┌──────────────────────────────┐
  │ Pi Zero 2 W             │                    │  macro-lens barrel (coaxial)  │
  │  ├ CSI ── camera ───────┼── looks out +Z ───▶│  (no sensor — optics only)    │
  │  ├ SPI ── 1.69" display │                    │  LED ring  ◀── V+ (PWM dim)   │
  │  ├ I²S ── mic + amp/spk  │   ┌── pogo×6 ──┐   │  ID EEPROM (I²C @0x50)        │
  │  ├ I²C ── (to cartridge) │◀──┤ interface  ├──▶│  CD# tie-to-GND, INT (shutter)│
  │  ├ GPIO ─ encoder       │   └────────────┘   └──────────────────────────────┘
  │  └ PMIC (IP5306) + USB-C │
  └─────────────────────────┘
```
Pinout and mechanical contract: see [`connector-spec.md`](connector-spec.md).

---

## 6. Open decisions remaining after Phase 1

| Item | Status | When it must close |
|---|---|---|
| Exact display module P/N + true active-area dims | starting from 1.69" 240×280 ST7789V generic; datasheet TBD | Phase 3 (drives bezel) |
| LED ring: LED count / driver (direct-PWM vs. tiny constant-current) | budget-capped at ≤150 mA | Phase 4 |
| PMIC final part (IP5306 vs. discrete) | leaning IP5306 | Phase 4 |
| Dovetail profile geometry | seed values in connector-spec §5; **optimized in Phase 2** | Phase 2 |
| License (MIT vs CERN-OHL-S) | deferred | Phase 7 |

---

## 7. Note on Phase 4 depth (updates the Phase 0 finding)

Phase 0 found **no KiCad** in the environment. Per review, **KiCad will be installed**,
so Phase 4 target is upgraded from "documented schematic only" to **schematic +
footprints + BOM** as openable `.kicad_sch` / `.kicad_pcb`, validated/exported via
`kicad-cli`. Full routing is optional. It remains a **design, not a verified board** —
no fabricated/tested claims. (See the dated addendum in `tool-capabilities.md`.)

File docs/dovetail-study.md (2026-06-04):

# VARA Dovetail Connector — Optimization Study (Phase 2)

**Date:** 2026-06-03 · **The project's engineering centerpiece.**
Parametric source: `cad/connector/dovetail_lib.py` · generations: `cad/connector/genparams.py`
· analytics: `cad/connector/analysis.py` · artifacts: `cad/connector/{out,glb}/`,
`connector_male_v1.stl`, `connector_female_v1.stl`, `connector_assembled_v1.glb`.

> ## ⚠️ Honesty banner — read first
> - **No FEM is available in this environment** (see `tool-capabilities.md`). The detent
>   stress numbers are **first-order analytical hand-calculations (cantilever beam theory),
>   NOT FEA.** They are order-of-magnitude design guidance.
> - **No printer is in the loop.** Every fit/tolerance is **"validated-by-design,
>   print-ready," never tested.**
> - Material constants are **estimates** from typical CF-PA12 ranges, not a measured
>   datasheet. Each is marked *(est.)*.
> - **Marginal and failing generations are kept in the table** and drive the next change.
>   Nothing is silently discarded.

---

## 1. The problem (why this is a real multi-objective optimization)

The shared cartridge connector must simultaneously: **locate** the cartridge so its pads
*and* the optical axis land inside the pogo/optical budget (**±0.30 mm**, set by 0.5 mm
pogo compression — `connector-spec.md` §3.1); **slide smooth then lock positive**;
**survive thousands of cycles** in PA12-CF (wear + creep); **carry power/data**; and **be
printable** despite layer anisotropy and undercut overhangs. These objectives genuinely
fight: `stiffness ↔ printability`, `retention force ↔ insertion ease`, `tight fit
(alignment) ↔ wear life`, `wall thickness ↔ size`.

**Configuration decision (made before Gen 1):** **dual rails at Y = ±rail_offset**, not one
central rail. A single centered dovetail would collide with the pad array (Y = ±6.35) and
the optical bore (Ø14 @ Y=0) — both live down the centerline. Two outboard rails leave the
center clear, and the wide Y-separation strongly resists roll/pitch. Geometry gate
`req_central_channel_clear` enforces rail inner edge ≥ 7.0 mm so the optical bore stays free.

---

## 2. The two models

### Model A — Alignment (analytical bound)
For a feature at axial position `X_f` **inside** the bearing span `[0, rail_length]`, the
worst-case lateral error is bounded by clearance + dimensional tolerance and is **not**
amplified by rail tilt: a straight rail held to ±c at both span ends keeps every interior
point within ±c (linear interpolation of two values each ≤ c stays ≤ c). Amplification only
happens for features *outside* the span — hence the design rule **keep pads (X=6) and
optical axis (X=15) inside `rail_length`.**

```
E_align = flank_clearance + 2·print_tol      (worst-case, two printed halves)   ≤ 0.30 mm
```
`print_tol` = assumed per-part FDM tolerance *(est.)*. RSS alternative
`flank_clearance + √2·print_tol` is also computed (less conservative); we gate on worst-case.

### Model B — Detent snap (straight cantilever, end load) — **analytical, NOT FEA**
Classic snap-fit beam relations (Bayer/BASF snap-fit design guide):
```
ε_max = 3·t·δ / (2·L²)            F = E·b·t³·δ / (4·L³)        (= 3EIδ/L³, I = b·t³/12)
F_ins = F·(μ+tanθ)/(1−μ·tanθ)     F_ret = F·(μ+tanβ)/(1−μ·tanβ)
```
`t`=beam thickness, `δ`=snap deflection, `L`=beam length, `b`=beam width (=detent_w).
**Gen 1 has no finger** → the female mouth-lip *wall* flexes (`L=engage_depth=4`,
`t=wall_thk=2.4`). **Gen 2+** use a dedicated cantilever finger. There are **two detents
(one per rail)** → reported `F_ins`/`F_ret` are ×2.
`SF_yield = ε_yield/ε_max` (target ≥ 2 for cycle life); `SF_interlayer = k·ε_yield/ε_max`
(if the beam bends *across* print layers — the FDM anisotropy case).

### Assumed constants — CF-PA12 on FDM *(estimates, not measured)*
| Symbol | Value | Basis |
|---|---|---|
| `E_flex` | **5000 MPa** *(est.)* | CF-PA12 spans ~3000–8000 MPa |
| `ε_yield` | **2.5%** *(est.)* | CF fill embrittles vs neat PA12 (~10%+) |
| `k_interlayer` | **0.50** *(est.)* | interlayer Z-strength ~40–60% of in-plane |
| `μ` | **0.25** *(est.)* | PA12-CF self-friction |
| `θ_insert / β_retain` | **30° / 60°** | lead ramp / retention ramp |

---

## 3. Two kinds of gate (don't conflate them)
- **Geometry gates (forge `REQUIREMENTS`, run on real built solids):** captive, clearance
  present, central channel clear, within cartridge envelope, min wall, both solids valid +
  watertight. **All six generations pass 6/6 and are watertight** — i.e. every generation is
  a *buildable, valid* part. Gen 1 is geometrically fine yet **functionally catastrophic**.
- **Functional gates (analytical, Models A/B):** the ±0.30 mm budget and the snap SFs.
  This is where the generations actually differ.

---

## 4. Generation table

Functional numbers from `analysis.py` (`cad/connector/out/analysis.txt`); geometry from
`forge build`. `c`=flank_clearance, `δ`=detent_depth, `E_w`=worst-case alignment error.

| Gen | What changed | Why (problem the previous gen exposed) | c / tol | E_w ≤0.30 | finger L×t | δ | ε_max | SF_y | SF_z | F_ins / F_ret (N) | Geom | **Verdict** |
|----:|---|---|---|---|---|---|---|---|---|---|---|---|
| **1** | baseline = spec seed | — (establish baseline) | 0.20/0.10 | **0.40 NO** | none (wall flexes) 4×2.4 | 0.60 | **13.5%** | 0.09 | 0.05 | **1253 / 4531** | 6/6 wt | **FAIL align+stress** |
| **2** | + dedicated cantilever finger | Gen1 detent over-strains the stiff lip wall by ~5× and needs 1253 N to insert (would shatter) | 0.20/0.10 | 0.40 NO | 12×1.2 | 0.60 | 0.75% | 3.33 | 1.67 | 5.8 / 21.0 | 6/6 wt | **FAIL align+interlayer** |
| **3** | tighten c 0.20→0.15; declare calibrated print-tol ±0.075 | Gen2 alignment still 0.40 > 0.30 | 0.15/0.075 | **0.30 (=budget)** | 12×1.2 | 0.60 | 0.75% | 3.33 | 1.67 | 5.8 / 21.0 | 6/6 wt | **FAIL interlayer** *(align marginal, zero margin)* |
| **4** | δ 0.60→0.45; lead-in 1.0→1.2 | Gen3 finger fails interlayer SF (1.67<2); tight c risks bind on insertion | 0.15/0.075 | 0.30 (=budget) | 12×1.2 | 0.45 | 0.56% | 4.44 | **2.22** | 4.4 / 15.7 | 6/6 wt | **PASS** *(but zero align margin)* |
| **5** | finger 12×1.2→13×1.0; c 0.15→0.12 | Gen4 has no alignment margin; want robust interlayer SF | 0.12/0.075 | **0.27** | 13×1.0 | 0.45 | 0.40% | 6.26 | 3.13 | 2.0 / **7.2** | 6/6 wt | **PASS** *(lock now light)* |
| **6** | finger t 1.0→1.1, δ 0.45→0.50, rail 24→26 | Gen5 retention dropped to ~7 N (soft lock); buy margin everywhere | 0.13/0.075 | **0.28** | 13×1.1 | 0.50 | 0.49% | 5.12 | 2.56 | 2.9 / **10.6** | 6/6 wt | **PASS ✓ resolved** |

### Reasoning, generation by generation
- **Gen 1 — baseline.** Build the seed verbatim. Geometrically valid, but the detent is
  formed by flexing the 2.4 mm-thick, 4 mm-tall female lip wall 0.6 mm: ε ≈ **13.5%**, ~5×
  the estimated yield strain, with an absurd ~1253 N insertion force. It would fracture
  before assembling. Alignment 0.40 mm also blows the budget. *Two problems exposed:
  detent stiffness, alignment.*
- **Gen 2 — give the detent its own spring.** Replace wall-flex with a dedicated cantilever
  snap finger (L=12, t=1.2). Strain drops to 0.75%, in-plane SF 3.3, insertion a sane 5.8 N.
  But **interlayer SF = 1.67 < 2** (if the finger bends across print layers) and alignment
  is still 0.40. *Exposed: print-orientation sensitivity of the thin finger; alignment.*
- **Gen 3 — attack alignment.** Tighten clearance to 0.15 and **declare a print-tolerance
  requirement** of ±0.075 mm/part (calibrated printer). E_align lands at **exactly 0.30 —
  on the budget, zero margin.** Kept as a marginal finding. Interlayer SF still 1.67.
  *Exposed: the fit is now tight (bind risk) and still no interlayer margin.*
- **Gen 4 — lower the detent, ease insertion.** Drop δ to 0.45 (cuts strain and force) and
  grow the lead-in chamfer to 1.2 mm. Interlayer SF clears 2.0 (**2.22**); first **PASS**.
  But alignment margin is still zero (0.30). *Exposed: no alignment headroom.*
- **Gen 5 — buy alignment margin + robust interlayer.** Make the finger longer & thinner
  (13×1.0) to push strain to 0.40% (interlayer SF 3.13) and tighten c to 0.12 → E_align
  **0.27, real margin**. Cost: retention force fell to **7.2 N** — a soft lock. *Exposed:
  the retention↔strain tradeoff went too far toward soft.*
- **Gen 6 — resolved compromise.** Trade a little strain margin back for lock feel: finger
  t 1.1, δ 0.50 → SF_y 5.1 / SF_z 2.56 (both comfortably ≥2) and **F_ret ≈ 10.6 N** (firm,
  positive) with **F_ins ≈ 2.9 N** (easy). Lengthen the rail to 26 mm so pads (6) and
  optical (15) sit well inside the bearing with roll headroom; c 0.13 keeps E_align at
  **0.28** with margin. **All functional and geometry gates pass.**

---

## 5. The printability ↔ strength tension — resolved

The undercut flanks (55° from base = 35° from vertical) and the thin snap finger pull
against each other across print orientation:

| Orientation | Flank faces | Snap finger bending | Sliding-face finish |
|---|---|---|---|
| **Rail axis vertical (X ∥ build-Z)** ✅ chosen | constant cross-section → **vertical walls, NO support on functional faces** | finger bends **across layers** → interlayer case applies → must hold SF_z ≥ 2 | layer lines run along slide axis (rings); acceptable, light |
| Flat on bed (X horizontal) ✗ | undercut flanks become 35°-from-vertical **overhangs needing support inside the groove → wrecks sliding faces** | finger bends in-plane (stronger) | better, but flanks ruined |

**Resolution:** print **rail-axis-vertical** to keep all sliding/flank faces support-free,
and *design the finger to survive the interlayer penalty* (that is exactly why Gen 4→6
target `SF_interlayer ≥ 2`, not just in-plane SF). The 35° overhang is *within* the ~45°
FDM self-support limit anyway, and in this orientation the flanks aren't overhangs at all —
so we did **not** need to raise `dovetail_angle` for printability (a lever we considered and
rejected — see dead ends).

---

## 6. Dead ends & rejected levers (the record is a deliverable)
- **Single central dovetail** — rejected before Gen 1: collides with pads + optical bore.
- **Raising `dovetail_angle` for printability** — considered as a way to reduce flank
  overhang; **unnecessary** once we commit to rail-axis-vertical printing (flanks become
  vertical walls regardless of angle). Left at 55° for capture/material balance.
- **Tightening clearance alone to hit alignment** — Gen 3 showed c=0.15 only reaches the
  budget *exactly* and increases bind risk; needed the print-tolerance requirement +
  lead-in/feel work (Gen 4–6), not just a smaller number.
- **Maximizing strain safety factor** — Gen 5 (SF_z 3.13) made the lock too soft (7.2 N).
  More margin is not free; Gen 6 deliberately spends some to get a firm 10.6 N lock.
- **Mechanically staggered pin lengths for hot-plug** — deferred to firmware sequencing
  (connector-spec §4.2); can't validate timing without hardware.

---

## 7. Resolved profile (Gen 6) — feeds back into `connector-spec.md` §5 [STUDY]

| Param | Resolved | | Param | Resolved |
|---|---|---|---|---|
| dovetail_angle | 55° | | detent_depth | 0.50 mm |
| flank_clearance | 0.13 mm | | finger_len × thk | 13 × 1.1 mm |
| rail_length | 26 mm | | lead_in_chamfer | 1.2 mm |
| wall_thk | 2.4 mm | | engage_depth | 4.0 mm |
| **Print requirement** | rail-axis-vertical; per-part tol ≤ ±0.075 mm | | rail_offset / mouth_w | 13 / 4 mm |

**Resolved performance (analytical, validated-by-design — NOT tested):**
alignment **E = 0.28 mm ≤ 0.30** with margin (pads & optical inside the 26 mm bearing);
detent **ε = 0.49%**, **SF_yield 5.1**, **SF_interlayer 2.56**; **insertion ≈ 2.9 N**
(easy), **retention ≈ 10.6 N** (firm positive lock); geometry **6/6 gates, watertight**.

---

## 8. Outputs
- **Resolved STLs:** `cad/connector/connector_male_v1.stl`, `connector_female_v1.stl`
- **Resolved assembled glTF:** `cad/connector/connector_assembled_v1.glb`
- **Evolution GLB set (Three.js clip, ~5 KB each):** `cad/connector/glb/gen1…gen6.glb`
- **Per-gen diagnostics + STL:** `cad/connector/out/gen1…gen6/`
- **Analytical record:** `cad/connector/out/analysis.txt`
- **Regenerate:** `forge build cad/connector/genN.py` · `python cad/connector/analysis.py`

## 9. Honest limitations
1. Stress is **beam theory, not FEA** — a real detent has stress concentrations at the
   finger root the straight-beam formula understates; treat SFs as guidance, hold ≥2.
2. Material constants are **estimates**; the true CF-PA12 modulus/strain from a chosen
   filament datasheet should replace them before any fab decision.
3. Alignment assumes ideal straight rails; real print warp/creep over thousands of cycles
   is **not** modeled — the design mitigates it by decoupling retention (finger) from the
   locating fit (flanks), so flank wear loosens *feel* before it loses *location*.
4. No fit, force, or cycle-life claim here has been **measured**.

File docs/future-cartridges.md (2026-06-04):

# Future cartridges — architecture only (NOT built)

Scope discipline: **one** hero cartridge gets finished — the vision/macro
lens. Every other cartridge idea lives here as *architecture only*, to prove the platform
generalises without becoming a graveyard of half-built modules. Nothing below is modelled,
and nothing below should be modelled unless a future phase explicitly re-opens scope.

The test each must pass: **does it conform to the frozen interface contract**
(`connector-spec.md` v0.2) without changing it? The contract gives every cartridge:
`V+ (3V3 switched ≤150 mA) · GND · I²C SDA · I²C SCL · CD# · INT`, an EEPROM ID at `0x50`,
the dual-rail dovetail envelope, and the ±0.28 mm alignment budget. If a sense fits in that
envelope, the architecture holds.

| Cartridge (architectural) | Sensor (representative) | How it uses the 6-pin contract | Why it fits unchanged |
|---|---|---|---|
| **Thermal sense** | MLX90640 32×24 IR array | I²C sensor on SDA/SCL; INT = frame-ready; powered from V+ | I²C @ ≤1 MHz, low-bandwidth — exactly what the contract carries. No optics needed (its own lens). |
| **Air-quality / environment** | BME688 (gas/VOC/T/RH/P) | I²C on SDA/SCL; V+ powers it; INT optional | Pure I²C, microwatts. The instrument "smells" instead of seeing. |
| **Audio / ultrasonic** | I²S or analog MEMS + a tiny MCU exposing I²C | MCU does the DSP, presents results over I²C; INT on detection | The 6-pin bus can't carry raw I²S fast enough → a cartridge-side MCU summarises and speaks I²C. Documents the contract's *limit* honestly. |

**What makes the vision cartridge the special case** (and why it was chosen as the hero):
it is the only one that *reuses the core's eye* through swappable optics, like a microscope
objective — so it exercises the optical-axis coaxiality constraint (the ±0.28 mm budget
governing the bore, not just the pads). The others are self-contained I²C sensors and are, if
anything, *easier* — which is the point: the hard case is built, the rest follow by contract.

**The audio cartridge is the honest edge case.** Raw audio/ultrasonic streaming exceeds the
6-pin low-speed contract, so that cartridge would need a small MCU to do on-cartridge DSP and
report over I²C. That's not a flaw in the architecture — it's the architecture telling you
where the boundary is. CSI-bandwidth senses (more cameras, depth) stay in the core, like the
vision camera does.

> None of this is built. It exists to show the connector contract was designed once and holds.

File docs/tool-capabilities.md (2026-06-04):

# Tool Capabilities — Phase 0 Probe

**Date:** 2026-06-03
**Purpose:** Empirically establish what each tool can actually do *before* committing
ambition — the project's Phase 0. Every claim below is backed by a command that was
run and its observed output. Nothing here is assumed.

> **Headline:** The plan named three MCPs (FreeCAD, Blender, KiCad). Two of those are
> dead or absent for our purposes. The real CAD engine in this environment is the
> **`forge-cad` / build123d** pipeline, which is *better* than the thin FreeCAD MCP
> would have been. There is **no KiCad** capability of any kind, which sets a hard
> ceiling on Phase 4.

---

## Summary table

| Capability the plan wants | Tool the plan named | Reality | Verdict |
|---|---|---|---|
| Parametric CAD, boolean, regen, STL | FreeCAD MCP | MCP exposes only `check_connection` + `test_echo`; app offline | ❌ unusable — **route around** |
| (same) | **forge-cad / build123d 0.10.0** | Full parametric build, booleans, param regen, requirement gates, diagnostics, STL/STEP/3MF/BREP/glTF, 6-view render | ✅ **primary CAD engine** |
| FEM / stress check | FreeCAD FEM | Not present anywhere (no FreeCAD FEM access, no Calculix, build123d has none) | ❌ → analytical estimate, documented |
| Animation, decimation, glTF export | Blender MCP | Rich (arbitrary Python, scene, screenshot); **app must be launched** (Blender.app installed, addon currently offline) | ⚠️ available once user starts Blender |
| Schematic / footprints / netlist / BOM | KiCad MCP | No MCP, no `kicad-cli`, KiCad **not installed** | ❌ no programmatic KiCad at all |

---

## 1. FreeCAD MCP — ❌ unusable for CAD

**Commands run**

```
mcp__freecad__check_freecad_connection
  → {"freecad_socket_exists": false, "status": "FreeCAD not running.
     Please start FreeCAD and switch to AI Copilot workbench"}

mcp__freecad__test_echo("VARA phase 0 probe")
  → "Bridge received: VARA phase 0 probe"
```

**What worked:** the MCP bridge process responds (echo round-trips).
**What failed / the ceiling:** Two things, either of which is disqualifying:
1. **The app is offline.** The bridge talks to a FreeCAD desktop instance running the
   "AI Copilot" workbench; that instance is not running. (FreeCAD.app *is* installed at
   `/Applications/FreeCAD.app`, so it *could* be launched — but see #2.)
2. **The MCP exposes no CAD operations.** The entire FreeCAD MCP surface is exactly two
   tools: `check_freecad_connection` and `test_echo`. There is **no** tool to create a
   sketch, add a constraint, extrude, boolean, change a parameter, or export an STL.
   Even with FreeCAD running, this MCP could not perform a single step of Phase 0's
   FreeCAD checklist.

**Decision:** Do not pursue the FreeCAD MCP. It is a connectivity stub, not a CAD
interface. Route all CAD through `forge-cad` (§2).

---

## 2. forge-cad / build123d — ✅ primary CAD engine (the route-around)

The genuine CAD capability lives in the local `forge-cad` pipeline:
`/Users/vs/Projects/forgecad/.venv` (build123d **0.10.0**), driven by the `forge` CLI.
This runs **headless** — no desktop app, no socket, fully scriptable and reproducible.

**Probe:** authored a parametric part — constrained sketch → extrude → **boolean
subtract** (thru-hole) → fillet — with a `PARAMS` dict and an assert-style `REQUIREMENTS`
gate, then built it, changed a driving parameter, and rebuilt.

**Gen 1** (`plate_w=40, hole_d=8`):
```
forge build probe.py
 bbox (mm)   40.00 x 24.00 x 6.00     volume 5.41 cm³   mass 6.7 g
 solids/faces/edges 1/11/27   watertight yes   requirements 1/1
 → diagnostics.json, probe.stl
```

**Gen 2** — changed `plate_w 40→60`, `hole_d 8→12`, rebuilt (regeneration test):
```
 bbox (mm)   60.00 x 24.00 x 6.00     volume 7.92 cm³   requirements 1/1
```
Geometry regenerated correctly from the new parameters; the requirement gate
(width-check + "boolean actually removed material") still passed. ✅

**Exports** (all succeeded, all non-trivial files, glTF magic verified `glTF\x02`):

| Format | Command | Result |
|---|---|---|
| STL  | `forge export stl …`  | 51 KB |
| STEP | `forge export step …` | 35 KB |
| 3MF  | `forge export 3mf …`  | 13 KB |
| glTF/GLB | `forge export glb …` | 19.5 KB, valid v2 binary |
| Preview PNG | `forge preview …` | 33.5 KB, real 6-view shaded render (hole visible in top/iso) |

**Full forge CLI surface:** `build`, `check` (diagnostics only), `diff` (compare two
diagnostics — for regression tracking between dovetail generations), `draw` (HLR
engineering drawings), `export`, `info`, `preview` (6-view), **`sweep`** (parameter
sweep validation gate).

**Diagnostics available** (read instead of eyeballing screenshots): volume, mass,
bbox, solids/faces/edges/shells/vertices counts, watertight flag, min-feature size,
per-requirement pass/fail.

**Skills layered on top** (in `forgecad/skills/`): `forge-cad`, `forge-assembly`
(joints/mates/interference — for core+cartridge fit checking), `forge-iterate`
(revision diffing — for the dovetail generations), `forge-manufacturing` (3MF + print
orientation + overhang/wall checks — Phase 3 design-for-AM), `forge-render-hero`
(presentation renders via Blender), `forge-vision-decompose`.

**Ceiling / what it does NOT do:**
- **No FEM/FEA.** Confirmed: no stress solver in forge, no FreeCAD FEM reachable, no
  Calculix on the system. The dovetail detent stress check (Plan §4.3) must be a
  **documented analytical estimate** (cantilever-snap beam model), explicitly labelled
  as an estimate — never a simulated result.
- **No printer in the loop.** All fit/tolerance claims remain "validated-by-design,
  print-ready," never "tested." (Honesty rule #1.)

**Verdict:** This fully replaces the FreeCAD MCP and exceeds what it could have offered.
`sweep` + `diff` + `REQUIREMENTS` map directly onto the dovetail generation study; GLB
export feeds the Three.js showcase directly.

---

## 3. Blender MCP — ⚠️ rich, but the app must be launched

**Command run**

```
mcp__blender__get_polyhaven_status
  → "Error checking PolyHaven status: Could not connect to Blender.
     Make sure the Blender addon is running."
```

**State:** Blender.app is installed (`/Applications/Blender.app/Contents/MacOS/Blender`),
but the BlenderMCP addon/socket is not currently serving, so live probing (import STL,
material, keyframes, render, glTF) could not be executed this session.

**Capability (from the registered tool surface, not yet exercised live):** the MCP
exposes `execute_blender_code` (**arbitrary Python** — i.e. anything bpy can do:
import STL, assign materials, keyframe, render, glTF export, decimate), plus
`get_scene_info`, `get_object_info`, `get_viewport_screenshot`, and asset integrations
(PolyHaven, Sketchfab, Hyper3D/Rodin, Hunyuan3D). Arbitrary-Python means the Plan's
Blender checklist (import → material → 2 keyframes → render → glTF) is well within reach
**once the addon is running**.

**Action item for the user (when we reach Phase 2/6):** launch Blender and start the
BlenderMCP addon server so the socket is live. I will re-probe with the actual
import→material→keyframe→render→glTF sequence at that point and record the result here.

**Mitigation that reduces Blender dependence:** `forge` already exports per-generation
GLB and renders 6-view previews headlessly. So the dovetail **evolution clip** can be
done two ways — (a) Blender morph/render (cinematic, needs Blender live), or (b) export
each generation as GLB and morph/crossfade them **in Three.js** at showcase time (no
Blender needed for the clip). We'll choose in Phase 2; option (b) de-risks the schedule.

---

## 4. KiCad — ❌ absent entirely (the hard ceiling)

**Findings**
- **No KiCad MCP.** Searched the full deferred-tool registry for kicad / schematic / pcb
  / netlist / symbol / footprint — zero matches.
- **No `kicad-cli`.** `which kicad-cli` → not found; no KiCad app bundle to source it from.
- **KiCad is not installed.** `/Applications` contains Blender.app and FreeCAD.app but
  **no KiCad.app**.

There is no path to programmatically create a KiCad project, place symbols, attempt
footprints, or export a netlist/BOM in this environment. This is the single most
schedule-affecting Phase 0 result.

---

## 5. Recommendation — how deep Phase 4 (electronics) can realistically go

The Plan's Risk table already anticipated this exact outcome: *"KiCad MCP is shallow →
PCB degrades to a documented schematic. Stated plainly."* Reality is one notch below
even that — there is no KiCad at all — so the honest plan is:

**Phase 4 floor (achievable now, do this):**
A **rigorously documented electrical design**, authored as text/markdown in
`electronics/` + `docs/electronics.md`:
- Per-subsystem **block diagram** and a complete **net list in tabular form** (every
  signal, source pin → destination pin, with the cartridge connector pinout from
  `connector-spec.md` as the contract boundary).
- Component selection with part numbers, the **cartridge ID/EEPROM** scheme, PMIC/charge
  topology, level/voltage rails, and a **BOM table** (CSV in `electronics/bom.csv`).
- ASCII/mermaid schematic-style diagrams where they clarify intent.
This is real engineering and fully honest; it is *not* a fabricated `.kicad_sch`.

**Phase 4 stretch (only if the user enables it):** If the user **installs KiCad** (gives
us `kicad-cli`), we can additionally:
- Hand-author `.kicad_sch` s-expression schematic files and **validate/export** them
  (ERC, netlist, BOM, PDF) via `kicad-cli` — a real, openable KiCad project.
- PCB layout/routing would still be largely manual-in-app work; we would *not* claim
  auto-routed boards. Board *outline* matched to enclosure mounts is feasible as a
  documented DXF/outline.

**What we will NOT do:** generate a fake netlist, a fake `.kicad_pcb`, or a rendered
board image we didn't actually produce. (Honesty rule #4.)

**Decision requested from the user (not blocking Phase 1):** install KiCad to unlock the
stretch path, or accept the documented-schematic floor? Either is defensible to a
robotics lab; the floor is honest and complete on its own.

---

## 6. Net effect on the phase plan

| Phase | Tooling reality | Change vs. plan |
|---|---|---|
| 2 — Dovetail study | forge `build`/`sweep`/`diff` + `REQUIREMENTS`; stress = analytical estimate | On track. FEM downgraded to documented estimate (anticipated). |
| 2/6 — Evolution clip & decimation | Blender (needs app live) **or** per-gen GLB morphed in Three.js | De-risked; Blender optional for the clip. |
| 3 — Mechanical | forge-cad + forge-assembly + forge-manufacturing | On track, headless. |
| 4 — Electronics | Documented schematic + netlist + BOM (floor); `kicad-cli` only if user installs KiCad | Degraded as the Risk table predicted; honest. |
| 6 — Showcase | forge GLB exports feed Three.js directly | On track. |

**Bottom line:** CAD and the showcase pipeline are strong and headless. Animation needs
the user to start Blender when we get there (with a no-Blender fallback). Electronics is
the constrained layer — plan for an excellent *documented* electrical design, and treat a
real KiCad project as a stretch contingent on the user installing KiCad.

---

## Addendum — 2026-06-03 (Phase 1 review)

**KiCad decision reversed by the user:** KiCad **will be installed**. Phase 4 target is
therefore upgraded from the documented-schematic *floor* to the *stretch* path:
**schematic + footprints + BOM** as openable `.kicad_sch` / `.kicad_pcb`, validated and
exported via `kicad-cli` (ERC, netlist, BOM, PDF). Full routing remains optional. It is
still a **design, not a verified/fabricated board** — honesty rule #1 stands.

Action when entering Phase 4: confirm `kicad-cli` is on PATH (`kicad-cli version`), then
re-probe the actual schematic→footprint→BOM→export chain and record the real ceiling here
before committing Phase-4 scope.

---

## Addendum 2 — 2026-06-03 (Phase 4 re-probe + install)

**Install (macOS).** KiCad was not installed and `kicad-cli` was absent (re-confirmed).
`brew install --cask kicad` **fetched** KiCad 10.0.3 (cached, ~1.4 GB) but its full cask
install **fails non-interactively**: moving the `demos` artifact to
`/Library/Application Support/kicad` needs `sudo` (no TTY for the password). **Routed around**
without sudo: mounted the cached DMG (`hdiutil attach`), copied `KiCad.app` to
`/Applications/KiCad/KiCad.app` (that dir is user-writable), symlinked the binary to
`/opt/homebrew/bin/kicad-cli`. `kicad-cli version` → **10.0.3**. (If a clean cask install is
wanted later, run `brew install --cask kicad` in a terminal so it can prompt for the password.)

**Empirical ceiling of `kicad-cli` 10.0.3** (tested, not assumed):
- Subcommands: `sch {erc, export{bom,netlist,pdf,svg,dxf,ps,python-bom}, upgrade}`, `sym`,
  `fp`, `pcb {…export/drc…}`, `jobset`.
- **It validates and exports; it does NOT create or place symbols** (no GUI scripting). So a
  schematic must be **hand-authored as `.kicad_sch` s-expression**, then driven through the CLI.
- **Verified chain (trivial 2-resistor probe):** hand-authored `.kicad_sch` with custom
  embedded symbols + **global-labels-placed-at-pin-endpoints** for connectivity →
  `kicad-cli sch erc` (runs, produces report), `sch export netlist` (**connectivity correct** —
  the shared net joined both pins), `sch export bom` (CSV). PDF/SVG export also available.
- Warnings seen (non-blocking): off-grid endpoints (fixed by snapping to the 1.27 mm grid);
  "symbol/footprint library not in project table" (cosmetic — symbols are embedded so the file
  opens; footprints are referenced by name for the BOM, not loaded).

**Real Phase-4 ceiling → delivered depth:** openable, ERC-checked **`.kicad_sch`** (core +
cartridge) + CLI-exported **netlist + BOM + PDF**. **PCB layout (`.kicad_pcb`) is NOT pursued**
— `kicad-cli pcb` can export/DRC but cannot place or route, so a board would need GUI/hand
authoring; per the brief, routing is "optional dessert" and we stop at the schematic depth.
This is a **design**, not a DRC-clean or manufactured board (see `electronics.md` banner).

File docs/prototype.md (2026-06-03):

# VARA — Functional Prototype (Phase 5)

**Date:** 2026-06-03 · Code: `app/` · Run: `python3 -m app.demo` (off-Pi) / `python3 -m app.main` (Pi).

> ## ⚠️ Honesty banner
> The pipeline is **logic-validated**, not **hardware-tested**. On this machine, camera,
> display, audio, control, cartridge, and the vision API are all **stubs** (each logs
> "STUB …" at startup). Stubs are structured as swappable drop-ins for the real drivers — they
> are **not** presented as working hardware, and the demo prints "LOGIC-VALIDATED … NOT
> hardware-tested." Secrets live in a **gitignored `.env`** (`.env.example` provided); no key
> is committed.

---

## 1. The pipeline
```
[jog press] → camera.capture() → display.show_viewfinder()
            → display.show_thinking() → vision.identify()  ──ok──→ display.show_result() + tts.speak()
                                                           └─err─→ display.show_error()  + tts.speak()
```
- **No on-device VLM** (Phase 1): `identify+explain` is a **cloud API call** (Anthropic Claude
  vision) with a cached system prompt. The Pi only captures, renders, and speaks.
- **Display** = the 240×280 viewfinder + caption split (architecture.md). Real ST7789 and the
  stub render the **identical** PIL layout — so `app/samples/*.png` are what the panel shows.

## 2. Cartridge init — the read-before-PWM contract (carried from Phase 4)
The shared V+ rail powers **both** the ID EEPROM and the LED ring, and LED dimming PWMs the V+
load switch (which power-cycles the EEPROM). So the order is mandatory:
```
init: cartridge.read_id()   # 1. read EEPROM @0x50 while V+ is steady
      cartridge.enable_power_pwm(0.6)   # 2. ONLY THEN may V+ be PWM'd for the LED
```
This is **enforced in code**: `enable_power_pwm()` raises `SequencingError` if `read_id()`
hasn't run. The demo proves the guard fires (`app/demo.py` step 2). A real driver must
preserve this ordering — the guard exists so a refactor can't silently break it.

## 3. What runs vs. what's stubbed

| Subsystem | Real driver (on Pi) | Stub (here) |
|---|---|---|
| Camera | `picamera2` (CSI) | synthetic test frame |
| Display | `ST7789` 240×280 SPI | identical PIL layout → PNG in `app/_out/` |
| Audio/TTS | `espeak-ng` via I²S amp | console + `tts_transcript.txt` |
| Control | `gpiozero` EC11 encoder | scripted events / stdin |
| Cartridge | `smbus2` EEPROM @0x50 + PWM | fake EEPROM record (ordering still enforced) |
| Vision | Anthropic Claude vision (needs key + Wi-Fi) | canned result, source="stub" |

Selection is automatic and **logged**: a subsystem runs real only if its lib imports and
`VARA_FORCE_STUBS` is off; otherwise stub. Never silently faked.

## 4. Handled failure modes (graceful degradation — verified in the demo)
Each maps to a typed `VisionError` → a clean error screen + short spoken message → return to
idle. **None crash the app.**

| Condition | Detected by | User sees |
|---|---|---|
| No Wi-Fi / host unreachable | socket preflight + `APIConnectionError` | "Offline — no network" |
| No API key | missing `ANTHROPIC_API_KEY` at startup | "No API key set" (degraded mode, per scan) |
| API timeout | `APITimeoutError` (timeout 12 s) | "Timed out — retry" |
| API/service error | `APIError` | "Service error — retry" |

Sample frames: `app/samples/sample_result.png` (success), `sample_error_offline.png`
(degradation), `sample_boot.png`. Full set regenerates to `app/_out/` via `python3 -m app.demo`.

## 5. Demo trace (logic path)
`python3 -m app.demo` runs: cartridge init (ID→PWM) → guard check (raises as expected) →
success scan → timeout → offline → no-key. 13 frames + a TTS transcript are produced; every
degradation path shows a clean error and continues.

## 6. Honest limitations
1. **Not hardware-tested** — no camera frame, panel, audio, I²C, or live API call was exercised
   on real hardware here. The real-driver classes are written against the documented APIs
   (`picamera2`, `ST7789`, `gpiozero`, `smbus2`, `anthropic`) but **unrun on a Pi**.
2. The **real vision call is unexercised** (no key in this environment); the success path used
   the stub. With a key + network, `RealVisionClient` is the default and the stub is bypassed.
3. GPIO pin numbers / overlays (SPI, I²C, I²S, camera) must be confirmed on the device.
4. Power sequencing of the IP5306 (auto-on, the shared button) is modeled in firmware logic,
   not validated electrically.

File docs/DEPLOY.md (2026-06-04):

# Deploying the showcase (`web/`)

`web/` is **static, no-build, CDN-pinned three.js** — it serves as-is from any static host.
All asset paths are relative; three.js loads from jsdelivr. Nothing to compile.

> These are prepared steps. Pick one; run it yourself when ready.

## Option A — Netlify Drop (simplest, no git, ~30 s)
1. Go to **https://app.netlify.com/drop**
2. Drag the **`web/`** folder onto the page.
3. You get an instant public URL (e.g. `https://vara-xxxx.netlify.app`). Done.
   - To get a custom subdomain or redeploys, claim the site (free account) and re-drag to update.

## Option B — GitHub Pages (versioned, from this repo)
First publish the repo (no remote yet):
```bash
# create the GitHub repo (needs `gh auth login` once)
gh repo create vara --public --source=. --remote=origin --push
```
Then serve only `web/` via a `gh-pages` branch:
```bash
git subtree push --prefix web origin gh-pages
```
Enable Pages: **repo → Settings → Pages → Source: Deploy from a branch → `gh-pages` / `/ (root)`**.
Live at `https://<your-user>.github.io/vara/` within a minute.

To update after edits to `web/`: re-run the `git subtree push` line.

*(Alternative for Pages without a second branch: a GitHub Action that uploads `web/` as the
Pages artifact — heavier setup; the subtree push is simpler for a no-build site.)*

## Option C — Cloudflare Pages / Vercel
Connect the repo, set **build command: none**, **output directory: `web`**. Deploys on push.

## Sanity check before sharing the link
- Open the URL, confirm all three scenes load (the GLBs are ~1.3 MB total) and there are no
  console errors.
- The honesty footer must be present: *"…validated-by-design, not hardware-tested…"*.

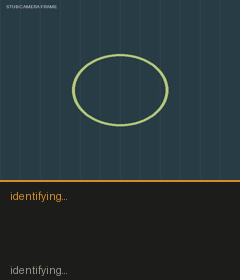
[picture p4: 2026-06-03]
web/assets/frames/sample_thinking.png

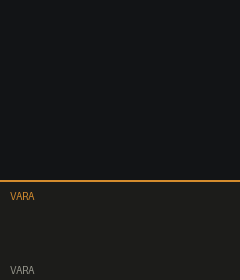
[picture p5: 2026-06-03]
web/assets/frames/sample_boot.png

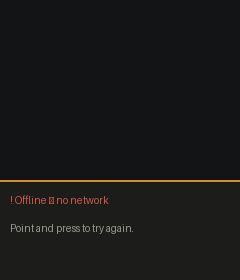
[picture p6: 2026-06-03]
web/assets/frames/sample_error_offline.png

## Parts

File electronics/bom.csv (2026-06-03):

Ref | Qty | Component | Value/Part | Package | Subsystem | Notes
A1 | 1 | Raspberry Pi Zero 2 W | RPi Zero 2 W | 40-pin header + CSI | Core/Compute | The real brain; runs capture->API->TTS pipeline
U2 | 1 | PMIC (charger+boost+pathmgmt) | IP5306 | ESOP-8 | Core/Power | Li-po charge + 5V boost + button + fuel gauge in one chip
U6 | 1 | LDO regulator 3V3 | AP2112K-3.3 (600mA) | SOT-23-5 | Core/Power | Derives +3V3_SYS for peripherals + switched cartridge rail
U5 | 1 | Load switch (current-limited) | TPS22918 | SOT-23-6 | Core/Cartridge | Switches/PWMs V+ to cartridge; ~150mA limit
DS1 | 1 | Display 1.69" IPS 240x280 | ST7789V SPI module | FPC + carrier | Core/Display | Active 28.0x32.6mm; SPI + DC/RST/BLK
MK1 | 1 | I2S MEMS microphone | SPH0645LM4H-B | 6-pin | Core/Audio | SEL->GND (left channel)
U4 | 1 | I2S Class-D amplifier | MAX98357A | QFN-16 | Core/Audio | Mono 3.2W; DIN from Pi PCM_DOUT
LS1 | 1 | Speaker | 8ohm 1W mini | Ø20mm | Core/Audio | Driven by U4
SW1 | 1 | Rotary encoder + push | EC11 (15mm) | THT | Core/Control | A/B quadrature + SW; the single primary control
J1 | 1 | USB-C receptacle | USB-C 16-pin (power) | SMD | Core/Power | Charge in; CC pulldowns R7/R8
J2 | 1 | Cartridge pogo connector (core) | 6-pos spring pins 2.54mm | Mill-Max-class | Core/Connector | The 6-pin contract: V+/GND/SDA/SCL/CD#/INT
J3 | 1 | CSI camera FFC connector | 15-pin 1mm FFC | SMD | Core/Camera | Pi camera ribbon (NOT through pogo)
CAM1 | 1 | Camera module | RPi Camera v2 / IMX219 | module | Core/Camera | Fixed in core; looks out optical bore
BT1 | 1 | Li-po battery | 3.7V 1500mAh | pouch | Core/Power | Runtime ~3.5h est (architecture.md)
R1 | 1 | I2C pull-up SDA | 4.7k | 0402 | Core/Connector | To +3V3_SYS
R2 | 1 | I2C pull-up SCL | 4.7k | 0402 | Core/Connector | To +3V3_SYS
R3 | 1 | CD# pull-up | 10k | 0402 | Core/Connector | Cartridge ties pin5 to GND
R4 | 1 | INT pull-up | 10k | 0402 | Core/Connector | Cartridge drives pin6 low
R5 | 1 | U5 EN pull-down | 100k | 0402 | Core/Cartridge | Default V+ off until Pi enables
R7 | 1 | USB-C CC1 pulldown | 5.1k | 0402 | Core/Power | Sink role
R8 | 1 | USB-C CC2 pulldown | 5.1k | 0402 | Core/Power | Sink role
C1 | 1 | Bulk cap +5V | 22uF | 0805 | Core/Power | Boost output decoupling
C2 | 1 | Bulk cap +3V3_SYS | 10uF | 0603 | Core/Power | LDO output
C3 | 2 | MCU/peripheral decoupling | 100nF | 0402 | Core | Local bypass (qty per rail as needed)
C4 | 1 | IP5306 input cap | 22uF | 0805 | Core/Power
U3 | 1 | I2C EEPROM (cartridge ID) | 24AA02E48 @0x50 | SOT-23-6/SOIC-8 | Cartridge | 128x8 + EUI-48; A0-A2->GND | WP->GND
D1 | 6 | LED ring | white 0603/PLCC | 0603 | Cartridge | Optional ring light; anode to V+
R6 | 6 | LED current-limit | 220ohm | 0402 | Cartridge | Per-LED; sized to <=150mA total cartridge budget
SW2 | 1 | Shutter button (optional) | tactile SPST | SMD | Cartridge | Drives INT (pin6) low; cartridge->core interrupt
PADS1 | 1 | Pogo pads (cartridge) | 6x flat gold pad Ø2.0 | PCB land | Cartridge | Mates J2; 2.54mm pitch at X=6

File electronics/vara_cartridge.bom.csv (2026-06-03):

Reference | Value | Footprint | QUANTITY | Description
LEDR1 | LED ring 6x + 6x 220R |  | 1
PADS1 | Pogo pads 6 (CART) |  | 1
R9 | 0R | Resistor_SMD:R_0402_1005Metric | 1
SW2 | Shutter (optional) |  | 1
U3 | 24AA02E48 @0x50 | Package_TO_SOT_SMD:SOT-23-6 | 1

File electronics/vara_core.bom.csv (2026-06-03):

Reference | Value | Footprint | QUANTITY | Description
A1 | RPi Zero 2 W |  | 1
BT1 | Li-po 3.7V 1500mAh |  | 1
CAM1 | RPi Camera v2 |  | 1
DS1 | ST7789 1.69in 240x280 |  | 1
J1 | USB-C recept |  | 1
J2 | Pogo 6p (CORE) |  | 1
J3 | CSI FFC 15p |  | 1
LS1 | Speaker 8R 1W |  | 1
MK1 | SPH0645LM4H |  | 1
R1,R2 | 4.7k | Resistor_SMD:R_0402_1005Metric | 2
R3,R4 | 10k | Resistor_SMD:R_0402_1005Metric | 2
R5 | 100k | Resistor_SMD:R_0402_1005Metric | 1
R7,R8 | 5.1k | Resistor_SMD:R_0402_1005Metric | 2
SW1 | EC11 |  | 1
U2 | IP5306 | Package_SO:ESOP-8 | 1
U4 | MAX98357A | Package_DFN_QFN:QFN-16 | 1
U5 | TPS22918 | Package_TO_SOT_SMD:SOT-23-6 | 1
U6 | AP2112K-3.3 | Package_TO_SOT_SMD:SOT-23-5 | 1

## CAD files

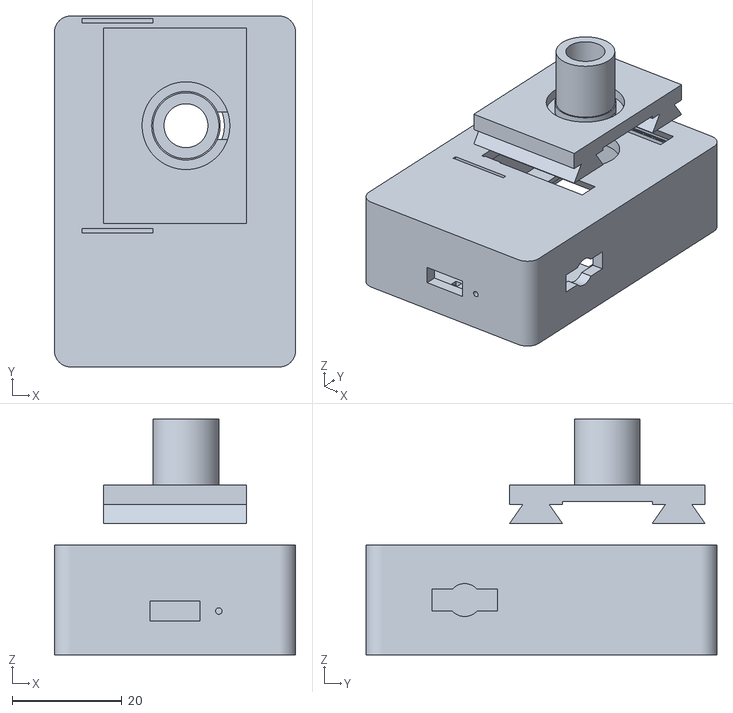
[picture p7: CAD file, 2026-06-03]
cad/out/assembly/vara_assembly.stl
44.0 x 64.0 x 43.0

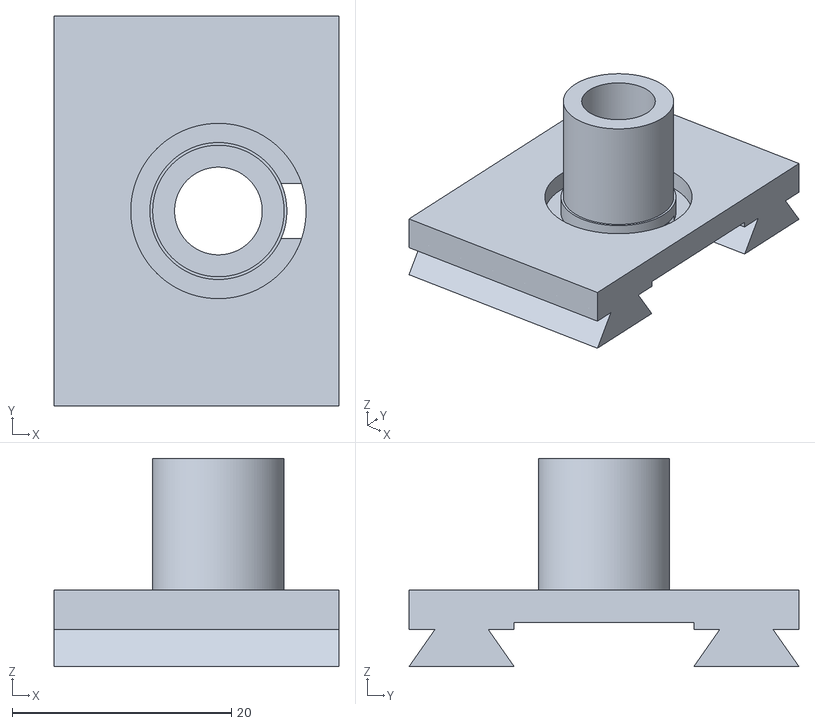
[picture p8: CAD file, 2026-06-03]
cad/cartridge/out/cartridge/vision_cartridge.stl
26.0 x 35.6 x 19.0

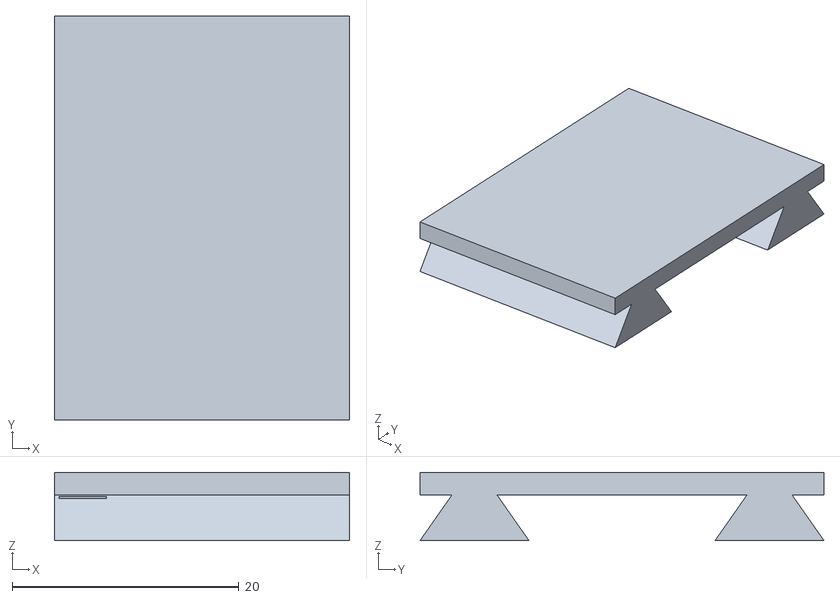
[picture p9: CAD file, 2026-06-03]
cad/connector/connector_male_v1.stl
26.0 x 35.6 x 6.00

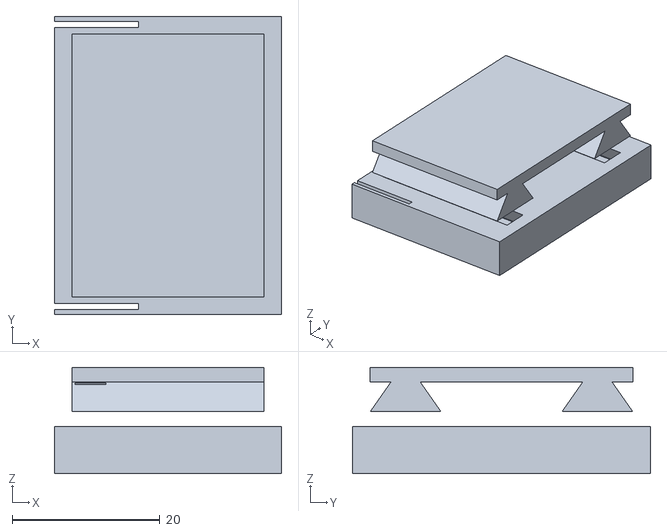
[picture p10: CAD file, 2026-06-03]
cad/connector/out/gen6/gen6.stl
30.8 x 40.4 x 14.4

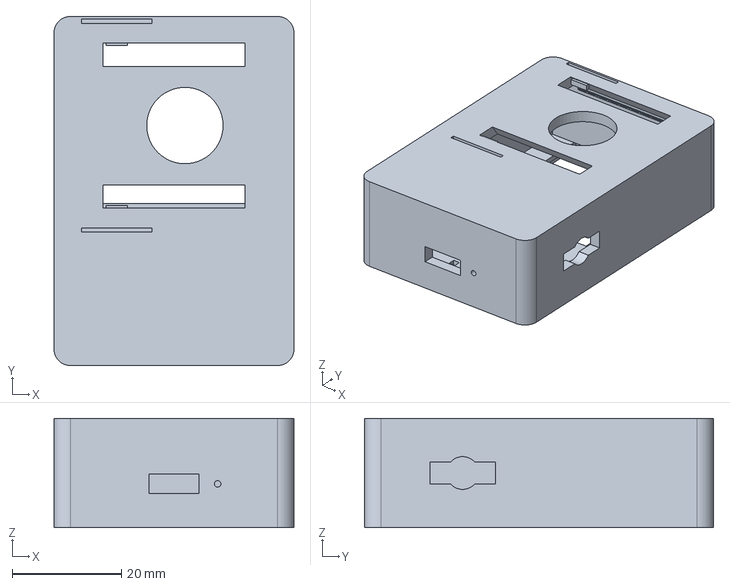
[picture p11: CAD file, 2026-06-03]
cad/core/core_body_v1.step
44.0 x 64.0 x 20.0 mm

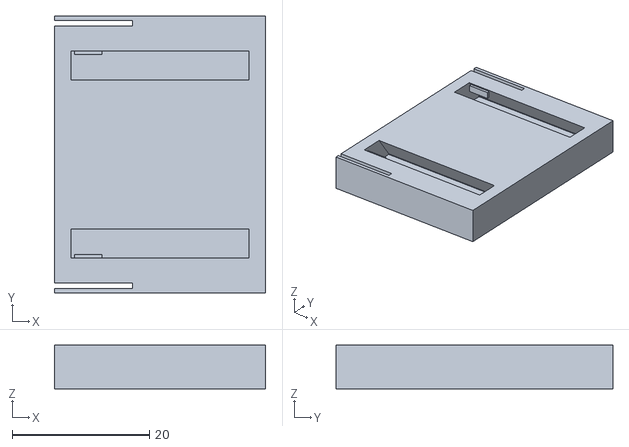
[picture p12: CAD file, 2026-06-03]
cad/connector/connector_female_v1.stl
30.8 x 40.4 x 6.40

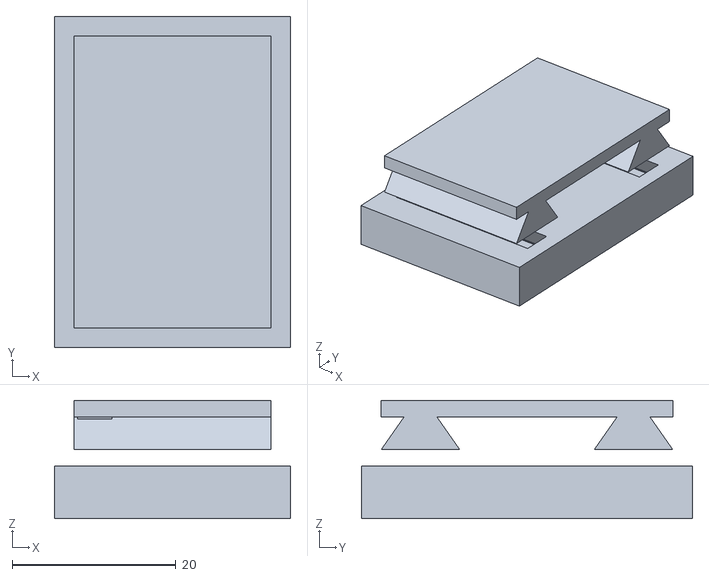
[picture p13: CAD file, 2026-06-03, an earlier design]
cad/connector/out/gen1/gen1.stl
28.8 x 40.4 x 14.4

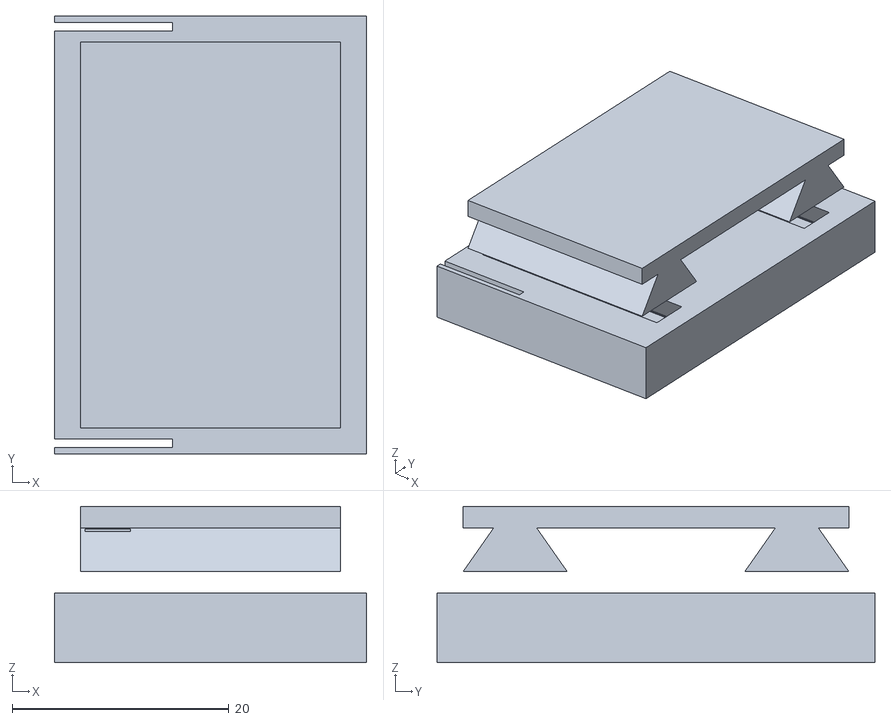
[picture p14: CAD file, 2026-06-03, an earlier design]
cad/connector/out/gen2/gen2.stl
28.8 x 40.4 x 14.4

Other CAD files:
cad/cartridge/vision_cartridge_v1.step
cad/core/out/core/core_body.stl
cad/connector/out/gen3/gen3.stl
cad/connector/out/gen4/gen4.stl
cad/connector/out/gen5/gen5.stl
cad/core/core_body_v1.stl

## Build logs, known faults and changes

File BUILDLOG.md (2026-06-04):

# VARA — Build Log

A decision record, phase by phase: the capability probes, the dead ends, and the honesty
calls. The point of this file is that the *process* is auditable — not just the result. Every
phase ended at a gate for review before the next began.

Honesty rules held throughout: never claim a fit is "tested" (only
"validated-by-design"); document dead ends, not just wins; never simulate tool output.

---

### Phase 0 — Capability probe (`docs/tool-capabilities.md`)
Probed the tools *before* committing ambition.
- **FreeCAD MCP**: dead — exposes only `check_connection` + `test_echo`, no CAD ops; app
  offline. Routed around it entirely.
- **Real CAD engine = `forge-cad` / build123d 0.10** (headless): parametric build, booleans,
  `REQUIREMENTS` gates, diagnostics, STL/STEP/3MF/glTF, `sweep`/`diff`. Verified live.
- **No FEM anywhere** → the dovetail stress check would have to be analytical, clearly labelled.
- **Blender MCP**: rich but needs the app running; the glTF showcase pipeline can avoid it.
- **KiCad**: absent (no MCP, no `kicad-cli`, not installed). Recorded as the hard ceiling for
  Phase 4 before designing anything.

### Phase 1 — Architecture & the frozen contract
- **Camera decision (RESOLVED):** camera lives in the **CORE**, not the cartridge. CSI is far
  too fast for a 6-pin pogo; putting it in the core keeps the interface low-speed and makes the
  vision cartridge "optics only." Bonus: the cartridge lens must be coaxial with the fixed
  camera, so the ±0.28 mm alignment budget governs the **optical axis**, not just the pads.
- **Reworked the seed pinout:** the proposed "ID resistor / 1-Wire" on pin 5 was dropped — the
  Pi Zero 2 W has no ADC, so a resistor divider needs an extra chip. Canonical ID became an
  **I²C EEPROM @0x50**; pin 5 became **CD# (cartridge-detect)**.
- **On-device VLM rejected** — and shown to be Pi-model-*independent*: no Pi runs a good
  identify-and-explain model, so it's a cloud call regardless, which *strengthens* the Zero 2 W
  choice. Documented the latency/Wi-Fi/key tradeoffs.
- Output: `architecture.md` + `connector-spec.md` (the single source of truth).

### Phase 2 — Dovetail optimization (the centerpiece, `docs/dovetail-study.md`)
Six problem-driven generations, each fixing what the last exposed (analytical, **not FEA**):
- **G1 baseline** — catastrophic: detent ε ≈ 13.5 %, ~1253 N to insert (would shatter), align
  0.40 mm. FAIL.
- **G2** dedicated cantilever finger → in-plane stress fine, but interlayer SF 1.67 < 2; align
  still 0.40. **G3** tighten clearance + declare a print-tolerance requirement → align lands
  *exactly* on 0.30 (kept as a marginal finding). **G4** lower detent → first PASS. **G5** buy
  alignment margin → lock went soft (7.2 N). **G6 resolved** — SF 5.1/2.56, 2.9 N insert,
  10.6 N retention, align 0.28 mm.
- **Dead ends recorded:** a single central rail (collides with pads/bore → dual rails); raising
  the dovetail angle for printability (unnecessary once printed rail-axis-vertical).
- **Honesty:** beam theory understates the real finger-root stress concentration → a protected
  root fillet, gated so a refactor can't quietly remove it.

### Phase 3 — Mechanical (`docs/mechanical.md`)
- Both parts **consume** the resolved connector via `dovetail_lib` primitives — the [STUDY]
  geometry is the single source, not re-derived.
- **Per-part print orientation** resolved a real tension: core front-down (snap finger loads
  *in-plane*, SF 5.1, beating the interlayer worst case); cartridge rail-axis-vertical
  (support-free flanks). Diagnostics caught two modelling defects (floating detent bumps,
  floating bosses — coincident faces don't weld).

### Phase 4 — Electronics (`docs/electronics.md`)
- **Re-probed first** (Phase-0 discipline): installed KiCad 10.0.3, but the full cask needs
  `sudo`; routed around by extracting the app + symlinking `kicad-cli`. Ceiling: `kicad-cli`
  validates/exports but **cannot place symbols** → schematics hand-authored as s-expression.
- **Floor + stretch both delivered:** netlist CSV + BOM, *and* openable `vara_core` /
  `vara_cartridge` `.kicad_sch` with CLI-exported netlist/BOM/PDF + ERC. Core 29 nets,
  cartridge 6 nets, **0 unconnected pins**; the 6-pin contract maps exactly on both sides.
- **PCB layout NOT pursued** — `kicad-cli` can't route. Stated plainly; **no fabricated copper**.

### Phase 5 — Functional prototype (`app/`, `docs/prototype.md`)
- Pipeline: jog-press → capture → cloud vision → 240×280 viewfinder+caption → speak.
- **Read-before-PWM guard encoded in code:** the shared V+ rail powers the EEPROM *and* the LED
  ring, and LED dimming PWMs V+ — so `enable_power_pwm()` raises `SequencingError` unless the ID
  was read first. The demo proves the guard fires.
- **Graceful degradation:** no-Wi-Fi / no-key / timeout / API-error → clean on-screen error,
  never a crash. Swappable HAL: real drivers vs clearly-logged stubs. **Logic-validated, not
  hardware-tested.**

### Phase 6 — Three.js showcase (`web/`) + iterative red-teaming
- Static, no-build, CDN-pinned three.js r160; consumes the real glTF + the real Phase-5 frames.
- Hardened over several review rounds: creased normals + matte PBR + SAO/bloom; a
  collision-free assembly path (verified `cartridge ∩ core = 2.7 mm³`); the enclosure enlarged
  to **actually fit the Pi Zero 2 W (65 mm)**; a full teardown with leader labels and honest
  designed/representative badges; camera-following light so every face reads; a no-cache server
  so edits are always seen. Dead ends found and fixed: a floating mid-body screw (explode loop
  overwrote seated Z), exposed dovetail rails (closed the socket), parts crossing (re-ordered to
  physical seated-Z).

### Phase 7 — Story & open-source
This README/BUILDLOG, the license decision, and the deploy of `web/`.

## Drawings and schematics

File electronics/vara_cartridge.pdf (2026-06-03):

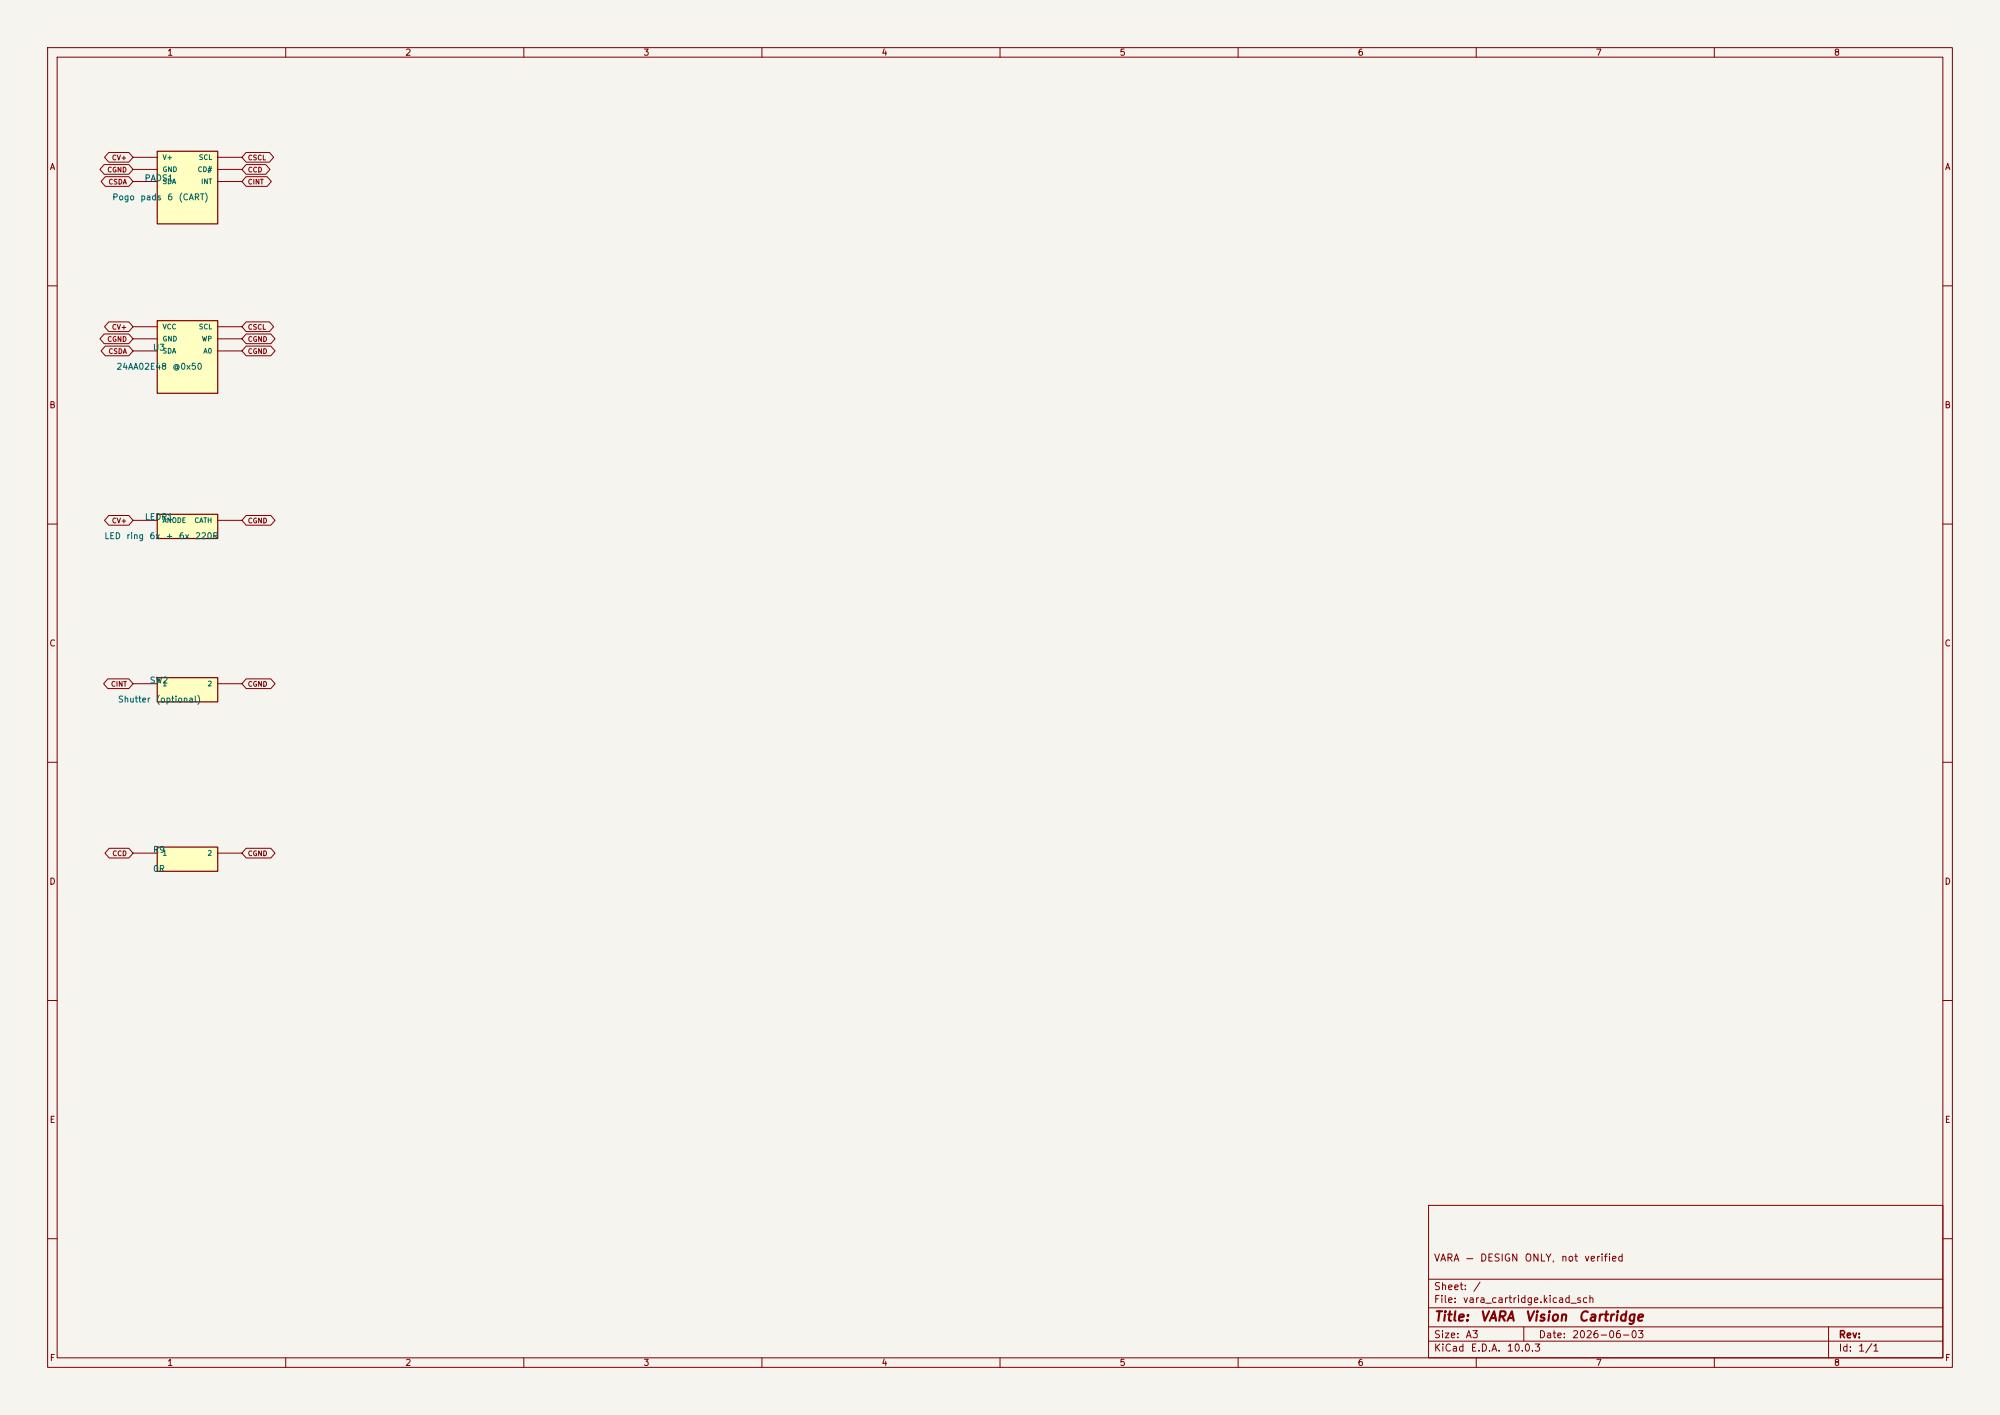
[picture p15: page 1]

VARA — DESIGN ONLY, not verified

Sheet: /
File: vara_cartridge.kicad_sch
Title: VARA Vision Cartridge

Size: A3 | Rev: | F Date: 2026-06-03
KiCad E.D.A. 10.0.3 | Id: 1/1

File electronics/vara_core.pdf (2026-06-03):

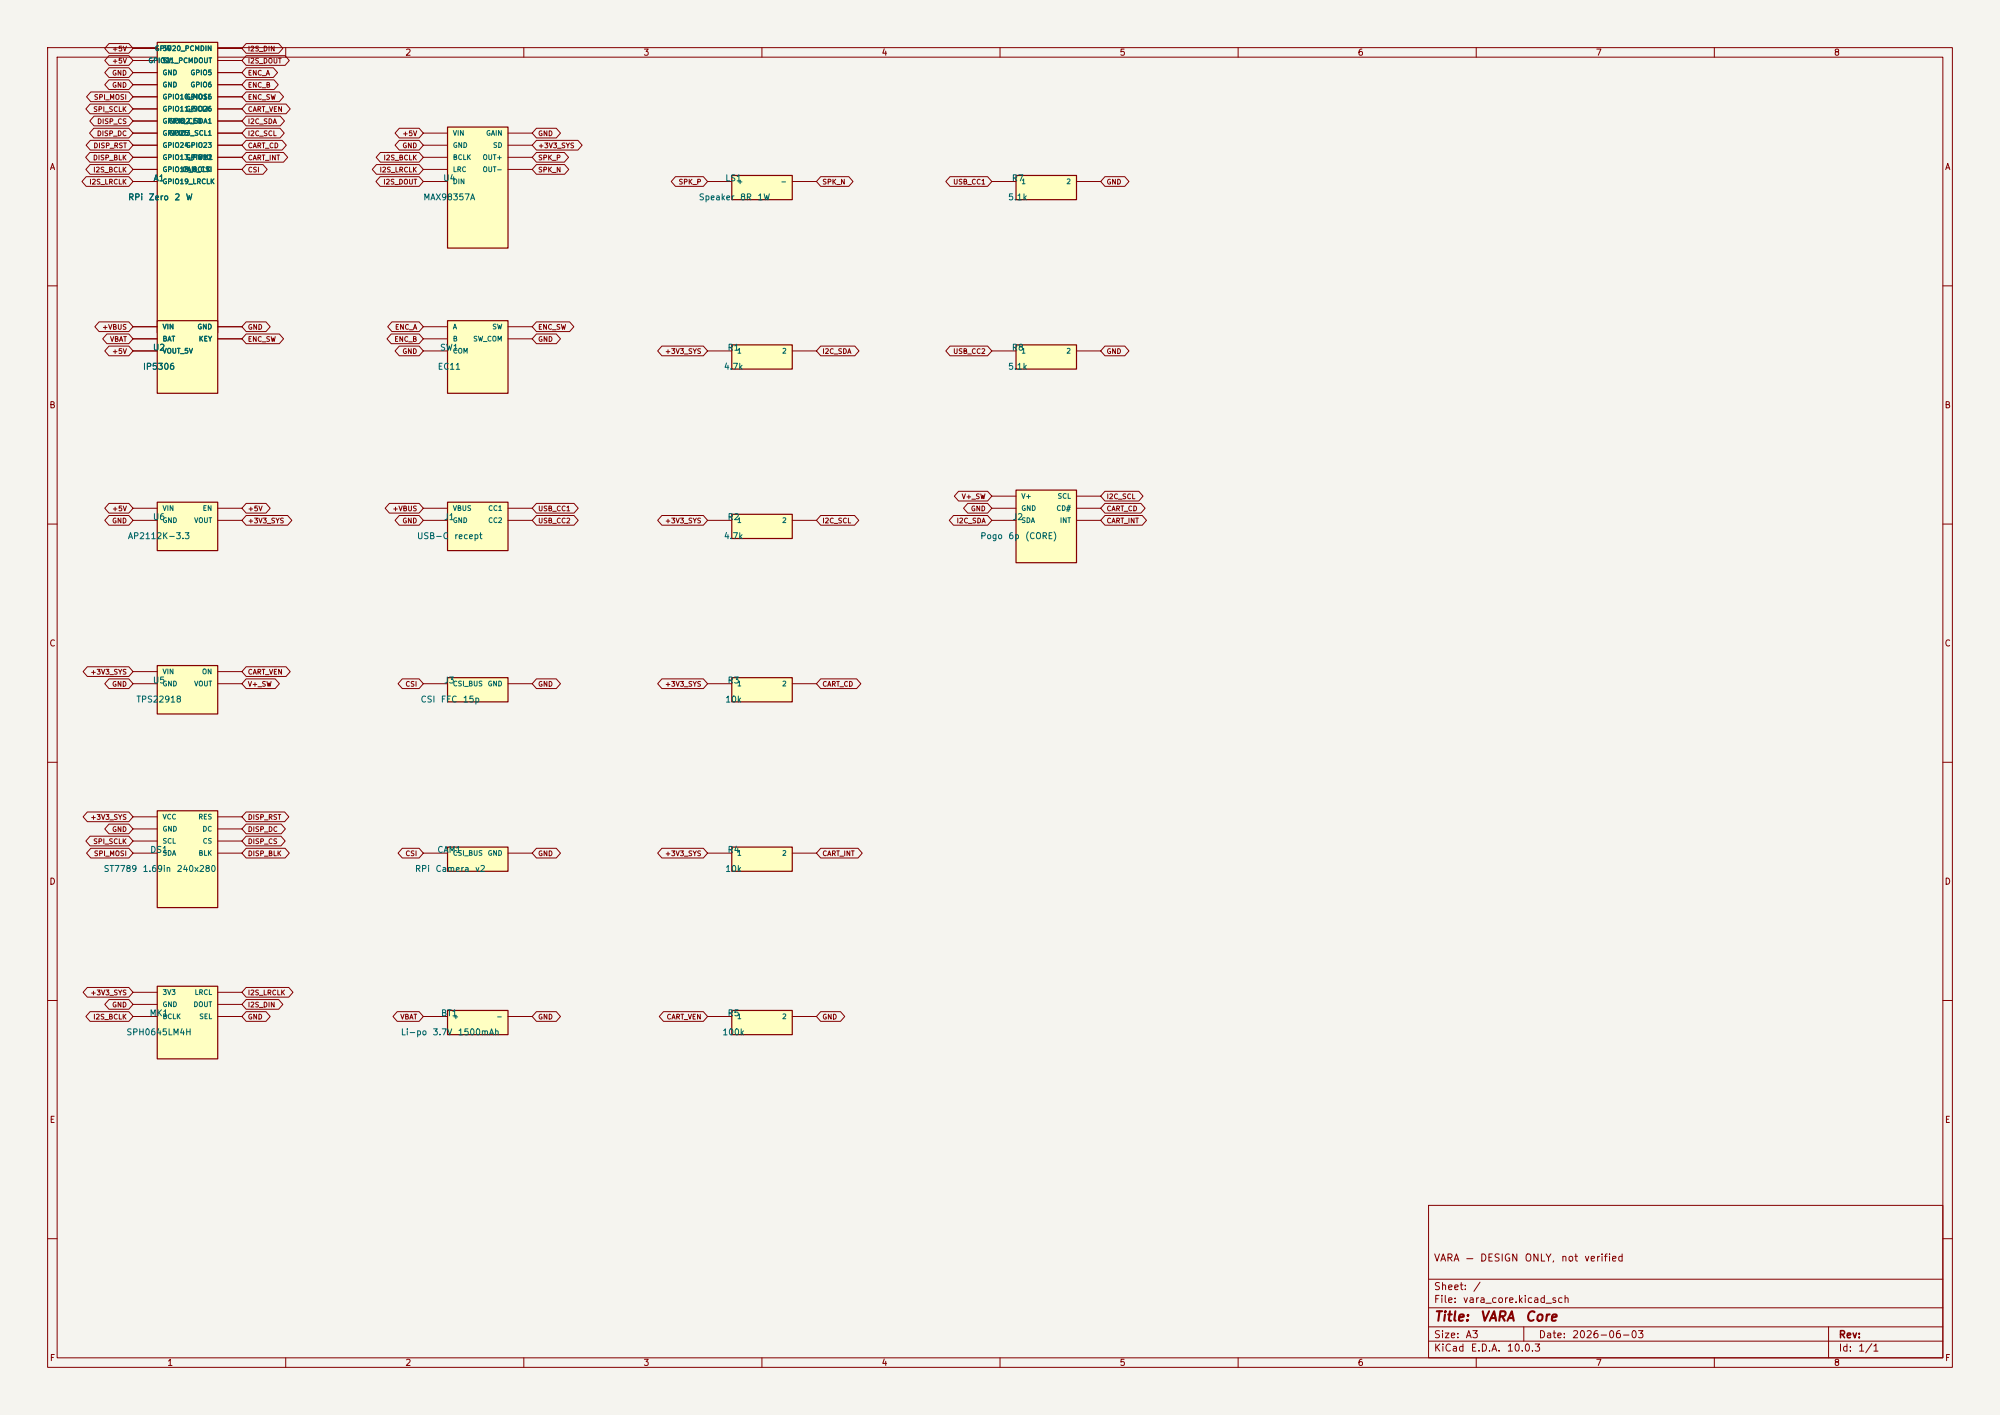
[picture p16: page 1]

VBUS J1 USB-C recept BLK

VARA — DESIGN ONLY, not verified

Size: A3 | Rev:
KiCad E.D.A. 10.0.3 | Id: 1/1 | F Date: 2026-06-03

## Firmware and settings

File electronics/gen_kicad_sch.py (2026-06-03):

"""Generate openable KiCad-10 .kicad_sch for VARA core + cartridge.

Approach (within the kicad-cli ceiling — see tool-capabilities.md Addendum 2): kicad-cli
cannot place symbols, so we hand-author valid s-expression schematics. Connectivity is by
GLOBAL LABELS placed at each pin endpoint — global labels join by name across the sheet, so
positions are cosmetic and nets are exact. Each component gets a generated rectangular symbol
with its real pins. Two separate sheets (core, cartridge); the 6-pin pogo is the boundary
(J2 on core, PADS1 on cartridge), pin-labelled identically per connector-spec v0.2.

This is a DESIGN. Not DRC-clean, not manufactured, not electrically verified.
"""
import uuid, sys

G = 1.27  # KiCad connection grid (mm)
def u(): return str(uuid.uuid4())
def snap(v): return round(round(v / G) * G, 4)

# component = dict(ref, value, fp, desc, pins=[(number, name, net), ...])
CORE = [
    dict(ref="A1", value="RPi Zero 2 W", fp="", desc="Compute module (40-pin header + CSI)", pins=[
        ("2","5V","+5V"),("4","5V","+5V"),("6","GND","GND"),("9","GND","GND"),
        ("19","GPIO10_MOSI","SPI_MOSI"),("23","GPIO11_SCLK","SPI_SCLK"),("24","GPIO8_CE0","DISP_CS"),
        ("22","GPIO25","DISP_DC"),("18","GPIO24","DISP_RST"),("33","GPIO13_PWM1","DISP_BLK"),
        ("12","GPIO18_BCLK","I2S_BCLK"),("35","GPIO19_LRCLK","I2S_LRCLK"),
        ("38","GPIO20_PCMDIN","I2S_DIN"),("40","GPIO21_PCMDOUT","I2S_DOUT"),
        ("29","GPIO5","ENC_A"),("31","GPIO6","ENC_B"),("36","GPIO16","ENC_SW"),
        ("37","GPIO26","CART_VEN"),("3","GPIO2_SDA1","I2C_SDA"),("5","GPIO3_SCL1","I2C_SCL"),
        ("16","GPIO23","CART_CD"),("32","GPIO12","CART_INT"),("CSI","CAM_CSI","CSI")]),
    dict(ref="U2", value="IP5306", fp="Package_SO:ESOP-8", desc="PMIC: charge+boost+path+button", pins=[
        ("VIN","VIN","+VBUS"),("BAT","BAT","VBAT"),("VOUT","VOUT_5V","+5V"),("GND","GND","GND"),("KEY","KEY","ENC_SW")]),
    dict(ref="U6", value="AP2112K-3.3", fp="Package_TO_SOT_SMD:SOT-23-5", desc="3V3 LDO 600mA", pins=[
        ("1","VIN","+5V"),("2","GND","GND"),("3","EN","+5V"),("5","VOUT","+3V3_SYS")]),
    dict(ref="U5", value="TPS22918", fp="Package_TO_SOT_SMD:SOT-23-6", desc="Load switch (V+ to cartridge)", pins=[
        ("1","VIN","+3V3_SYS"),("2","GND","GND"),("3","ON","CART_VEN"),("4","VOUT","V+_SW")]),
    dict(ref="DS1", value="ST7789 1.69in 240x280", fp="", desc="SPI IPS display", pins=[
        ("VCC","VCC","+3V3_SYS"),("GND","GND","GND"),("SCL","SCL","SPI_SCLK"),("SDA","SDA","SPI_MOSI"),
        ("RES","RES","DISP_RST"),("DC","DC","DISP_DC"),("CS","CS","DISP_CS"),("BLK","BLK","DISP_BLK")]),
    dict(ref="MK1", value="SPH0645LM4H", fp="", desc="I2S MEMS mic", pins=[
        ("3V3","3V3","+3V3_SYS"),("GND","GND","GND"),("BCLK","BCLK","I2S_BCLK"),
        ("LRCL","LRCL","I2S_LRCLK"),("DOUT","DOUT","I2S_DIN"),("SEL","SEL","GND")]),
    dict(ref="U4", value="MAX98357A", fp="Package_DFN_QFN:QFN-16", desc="I2S Class-D amp", pins=[
        ("VIN","VIN","+5V"),("GND","GND","GND"),("BCLK","BCLK","I2S_BCLK"),("LRC","LRC","I2S_LRCLK"),
        ("DIN","DIN","I2S_DOUT"),("GAIN","GAIN","GND"),("SD","SD","+3V3_SYS"),("OUTP","OUT+","SPK_P"),("OUTN","OUT-","SPK_N")]),
    dict(ref="SW1", value="EC11", fp="", desc="Rotary encoder + push", pins=[
        ("A","A","ENC_A"),("B","B","ENC_B"),("C","COM","GND"),("SW","SW","ENC_SW"),("SC","SW_COM","GND")]),
    dict(ref="J1", value="USB-C recept", fp="", desc="Charge in", pins=[
        ("VBUS","VBUS","+VBUS"),("GND","GND","GND"),("CC1","CC1","USB_CC1"),("CC2","CC2","USB_CC2")]),
    dict(ref="J3", value="CSI FFC 15p", fp="", desc="Camera ribbon (CSI-2 bus, not pogo)", pins=[
        ("CSI","CSI_BUS","CSI"),("GND","GND","GND")]),
    dict(ref="CAM1", value="RPi Camera v2", fp="", desc="Fixed camera, looks out optical bore", pins=[
        ("CSI","CSI_BUS","CSI"),("GND","GND","GND")]),
    dict(ref="BT1", value="Li-po 3.7V 1500mAh", fp="", desc="Battery", pins=[("+","+","VBAT"),("-","-","GND")]),
    dict(ref="LS1", value="Speaker 8R 1W", fp="", desc="Speaker", pins=[("+","+","SPK_P"),("-","-","SPK_N")]),
    dict(ref="R1", value="4.7k", fp="Resistor_SMD:R_0402_1005Metric", desc="I2C SDA pull-up", pins=[("1","1","+3V3_SYS"),("2","2","I2C_SDA")]),
    dict(ref="R2", value="4.7k", fp="Resistor_SMD:R_0402_1005Metric", desc="I2C SCL pull-up", pins=[("1","1","+3V3_SYS"),("2","2","I2C_SCL")]),
    dict(ref="R3", value="10k", fp="Resistor_SMD:R_0402_1005Metric", desc="CD# pull-up", pins=[("1","1","+3V3_SYS"),("2","2","CART_CD")]),
    dict(ref="R4", value="10k", fp="Resistor_SMD:R_0402_1005Metric", desc="INT pull-up", pins=[("1","1","+3V3_SYS"),("2","2","CART_INT")]),
    dict(ref="R5", value="100k", fp="Resistor_SMD:R_0402_1005Metric", desc="U5 EN pull-down", pins=[("1","1","CART_VEN"),("2","2","GND")]),
    dict(ref="R7", value="5.1k", fp="Resistor_SMD:R_0402_1005Metric", desc="USB CC1", pins=[("1","1","USB_CC1"),("2","2","GND")]),
    dict(ref="R8", value="5.1k", fp="Resistor_SMD:R_0402_1005Metric", desc="USB CC2", pins=[("1","1","USB_CC2"),("2","2","GND")]),
    dict(ref="J2", value="Pogo 6p (CORE)", fp="", desc="Cartridge interface — connector-spec v0.2", pins=[
        ("1","V+","V+_SW"),("2","GND","GND"),("3","SDA","I2C_SDA"),("4","SCL","I2C_SCL"),("5","CD#","CART_CD"),("6","INT","CART_INT")]),
]

CART = [
    dict(ref="PADS1", value="Pogo pads 6 (CART)", fp="", desc="Mates J2 — connector-spec v0.2", pins=[
        ("1","V+","CV+"),("2","GND","CGND"),("3","SDA","CSDA"),("4","SCL","CSCL"),("5","CD#","CCD"),("6","INT","CINT")]),
    dict(ref="U3", value="24AA02E48 @0x50", fp="Package_TO_SOT_SMD:SOT-23-6", desc="ID EEPROM", pins=[
        ("VCC","VCC","CV+"),("GND","GND","CGND"),("SDA","SDA","CSDA"),("SCL","SCL","CSCL"),
        ("WP","WP","CGND"),("A0","A0","CGND")]),
    dict(ref="LEDR1", value="LED ring 6x + 6x 220R", fp="", desc="Optional ring light (<=150mA budget)", pins=[
        ("A","ANODE","CV+"),("K","CATH","CGND")]),
    dict(ref="SW2", value="Shutter (optional)", fp="", desc="Drives INT low", pins=[("1","1","CINT"),("2","2","CGND")]),
    # CD# hard-tie to GND on the cartridge (presence): a 0R link
    dict(ref="R9", value="0R", fp="Resistor_SMD:R_0402_1005Metric", desc="CD# tie to GND (presence)", pins=[("1","1","CCD"),("2","2","CGND")]),
]


def gen_symbol(c):
    """Rectangular symbol with pins split left/right, on a 2.54 grid."""
    pins = c["pins"]; n = len(pins)
    nl = (n + 1) // 2
    rows = max(nl, n - nl)
    half_h = (rows) * 2.54
    w = 12.7
    ref = c["ref"]
    name = f"VARA:{ref}"          # lib_symbols key (matches instance lib_id)
    sub = ref                       # sub-symbol prefix drops the lib nickname
    s = [f'\t\t(symbol "{name}"',
         '\t\t\t(pin_numbers (hide yes)) (pin_names (offset 1.016))',
         '\t\t\t(exclude_from_sim no) (in_bom yes) (on_board yes)',
         f'\t\t\t(property "Reference" "{c["ref"][0] if c["ref"][0].isalpha() else "U"}" (at 0 {half_h+2.54} 0) (effects (font (size 1.27 1.27))))',
         f'\t\t\t(property "Value" "{c["value"]}" (at 0 {half_h+5.08} 0) (effects (font (size 1.27 1.27))))',
         f'\t\t\t(property "Footprint" "{c["fp"]}" (at 0 0 0) (effects (font (size 1.27 1.27)) (hide yes)))',
         f'\t\t\t(property "Datasheet" "" (at 0 0 0) (effects (font (size 1.27 1.27)) (hide yes)))',
         f'\t\t\t(property "Description" "{c["desc"]}" (at 0 0 0) (effects (font (size 1.27 1.27)) (hide yes)))',
         f'\t\t\t(symbol "{sub}_0_1"',
         f'\t\t\t\t(rectangle (start {-w/2} {half_h}) (end {w/2} {-half_h}) (stroke (width 0.254) (type default)) (fill (type background))))',
         f'\t\t\t(symbol "{sub}_1_1"']
    pin_local = {}
    for i, (num, pname, net) in enumerate(pins):
        if i < nl:                       # left side
            py = half_h - 1.27 - i * 2.54
            px = -w/2 - 5.08; ang = 0
        else:                            # right side
            py = half_h - 1.27 - (i - nl) * 2.54
            px = w/2 + 5.08; ang = 180
        pin_local[num] = (px, py)
        s.append(f'\t\t\t\t(pin passive line (at {px} {py} {ang}) (length 5.08) '
                 f'(name "{pname}" (effects (font (size 1.016 1.016)))) '
                 f'(number "{num}" (effects (font (size 1.016 1.016)))))')
    s.append('\t\t\t))')
    return name, "\n".join(s), pin_local


def gen_sheet(title, comps):
    root = u()
    libdefs, instances, labels = [], [], []
    # grid layout: columns of components
    per_col = 6
    for idx, c in enumerate(comps):
        name, sdef, pin_local = gen_symbol(c)
        libdefs.append(sdef)
        col, row = idx // per_col, idx % per_col
        ox = snap(40 + col * 60); oy = snap(40 + row * 35)
        ref = c["ref"]
        pin_lines = " ".join(f'(pin "{num}" (uuid "{u()}"))' for num, _, _ in c["pins"])
        instances.append(
            f'\t(symbol (lib_id "{name}") (at {ox} {oy} 0) (unit 1)\n'
            f'\t\t(exclude_from_sim no) (in_bom yes) (on_board yes) (dnp no) (uuid "{u()}")\n'
            f'\t\t(property "Reference" "{ref}" (at {ox-6} {oy-2} 0) (effects (font (size 1.27 1.27))))\n'
            f'\t\t(property "Value" "{c["value"]}" (at {ox-6} {oy+2} 0) (effects (font (size 1.27 1.27))))\n'
            f'\t\t(property "Footprint" "{c["fp"]}" (at {ox} {oy} 0) (effects (font (size 1.27 1.27)) (hide yes)))\n'
            f'\t\t{pin_lines}\n'
            f'\t\t(instances (project "vara" (path "/{root}" (reference "{ref}") (unit 1)))))')
        for num, pname, net in c["pins"]:
            px, py = pin_local[num]
            # KiCad flips Y when placing a symbol (symbol space +Y up, sheet +Y down):
            wx, wy = snap(ox + px), snap(oy - py)
            shape = "bidirectional"
            ang = 180 if px < 0 else 0
            labels.append(
                f'\t(global_label "{net}" (shape {shape}) (at {wx} {wy} {ang}) '
                f'(effects (font (size 1.016 1.016)) (justify {"right" if px<0 else "left"})) (uuid "{u()}"))')
    libsec = "\n".join(libdefs)
    return (f'(kicad_sch (version 20251024) (generator "vara_gen") (generator_version "10.0")\n'
            f'  (uuid "{root}")\n  (paper "A3")\n'
            f'  (title_block (title "{title}") (date "2026-06-03") (comment 1 "VARA — DESIGN ONLY, not verified"))\n'
            f'  (lib_symbols\n{libsec}\n  )\n'
            + "\n".join(instances) + "\n" + "\n".join(labels) + "\n"
            f'  (sheet_instances (path "/" (page "1")))\n)')


if __name__ == "__main__":
    open("vara_core.kicad_sch", "w").write(gen_sheet("VARA Core", CORE))
    open("vara_cartridge.kicad_sch", "w").write(gen_sheet("VARA Vision Cartridge", CART))
    print("wrote vara_core.kicad_sch + vara_cartridge.kicad_sch")

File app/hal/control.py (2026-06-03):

"""Control HAL. Real = EC11 jog encoder + push (gpiozero). Stub = scripted/stdin events.

The single primary control (Phase 1). Press = scan; long-press = shutdown; rotate = navigate.
"""
from __future__ import annotations
import enum, logging
log = logging.getLogger("vara.control")


class Event(enum.Enum):
    PRESS = "press"
    LONG_PRESS = "long_press"
    ROTATE_CW = "cw"
    ROTATE_CCW = "ccw"


class Control:
    def events(self):
        """Yield Event values until shutdown."""
        raise NotImplementedError


class GpioControl(Control):  # REAL — gpiozero on the Pi
    def __init__(self):
        from gpiozero import RotaryEncoder, Button  # noqa
        import queue
        self.q = queue.Queue()
        self.enc = RotaryEncoder(5, 6, max_steps=0)
        self.btn = Button(16, hold_time=1.5)
        self.enc.when_rotated_clockwise = lambda: self.q.put(Event.ROTATE_CW)
        self.enc.when_rotated_counter_clockwise = lambda: self.q.put(Event.ROTATE_CCW)
        self.btn.when_held = lambda: self.q.put(Event.LONG_PRESS)
        self.btn.when_released = lambda: self.q.put(Event.PRESS) if not self.btn.was_held else None
        log.info("control: REAL EC11 (GPIO5/6 + SW GPIO16)")

    def events(self):
        while True:
            ev = self.q.get()
            yield ev
            if ev is Event.LONG_PRESS:
                break


class StubControl(Control):  # STUB — replays a scripted event sequence (for the demo)
    def __init__(self, script):
        self.script = list(script)
        log.warning("control: STUB (scripted events: %s)", [e.value for e in self.script])

    def events(self):
        yield from self.script

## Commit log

2026-06-03 Phase 0: capability probe + repo scaffold
    - Scaffold vara/ repo structure (docs, cad, anim, electronics, app, web)
    - Persist VARA_BUILD_PLAN.md as on-disk source of truth
    - docs/tool-capabilities.md: empirical probe results + Phase 4 recommendation
    Probe findings:
    - FreeCAD MCP unusable (only check_connection+test_echo; app offline) -> route around
    - forge-cad/build123d 0.10.0 is primary CAD engine: parametric build, booleans,
    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
2026-06-03 Phase 1: architecture + frozen connector-spec contract
    - docs/architecture.md: subsystem choices locked
    - Pi Zero 2 W; 1.69in 240x280 ST7789V SPI; camera in CORE (CSI), optics-only cartridge
    - IP5306-class PMIC, 1500mAh; I2S audio; single jog encoder
    - on-device VLM rejected (Pi-model-independent) -> cloud vision API, tradeoff documented
    - power budget ~1.3W avg -> ~3.5h runtime (est., not measured)
    - docs/connector-spec.md v0.1: frozen interface contract
    - RH datum frame; +X removal, -X seat to hard stop at X=0; optical axis along +Z
    - 6-pin pogo: V+(3V3 switched <=150mA)/GND/SDA/SCL/CD#/INT; EEPROM ID @0x50
    - reworked seed pin5 (resistor/1-Wire) -> CD# detect (Zero 2 W has no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
2026-06-03 Phase 2: dovetail optimization study (centerpiece)
    Parametric dual-rail dovetail in build123d/forge; 6 problem-driven generations,
    each fixing a specific issue the prior exposed. Two gate types:
    - geometry gates (forge REQUIREMENTS on real solids): all 6 gens 6/6, watertight
    - functional gates (analytical, NOT FEA): +-0.3mm alignment budget + cantilever snap SF
    Arc:
    - G1 baseline: catastrophic (eps 13.5%, 1253N insert) + align 0.40 FAIL
    - G2 dedicated cantilever finger: stress ok in-plane, interlayer SF 1.67<2, align FAIL
    - G3 tighten c=0.15 + declare print-tol req: align lands exactly 0.30 (marginal), interlayer still fails
    - G4 lower detent 0.45 + lead-in: first PASS (interlayer 2.22) but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
    [connector_female_v1.stl, connector_male_v1.stl, gen1.stl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]
2026-06-03 Phase 3: mechanical design — core body + hero vision cartridge
    Both parts CONSUME the resolved Gen-6 connector geometry via dovetail_lib primitives
    (socket_cut/detent_add/male_rails); [STUDY] not re-opened. Refactored dovetail_lib to
    expose those primitives + attach the detent bumps solidly (no float) + add the PROTECTED
    finger-root fillet. Phase-2 gens regression-pass 6/6 watertight after refactor.
    Core body (44x64x20, 21.9g, 1 solid, watertight, 5/5):
    - 1.69in 240x280 bezel recess + active-area window; back female rail socket + detents;
    Ø14 optical bore coaxial w/ barrel + camera pocket; USB-C, jog-encoder aperture,
    I2S mic port, speaker grille; sealed electronics cavity + 4x M2.5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
    [core_body.stl, core_body_v1.step, core_body_v1.stl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]
2026-06-03 Phase 4: electronics — schematic + netlist + BOM (design, not verified)
    Phase-0 re-probe FIRST (tool-capabilities.md Addendum 2): kicad-cli was absent; installed
    KiCad 10.0.3 (brew cask fetch + manual app extraction — full cask needs sudo for
    /Library/Application Support; routed around by copying KiCad.app + symlinking kicad-cli).
    Empirical ceiling: kicad-cli validates/exports but cannot place symbols -> schematics
    hand-authored as .kicad_sch, driven through CLI. Verified trivial sch->netlist->BOM->ERC.
    Floor: electronics/netlist.csv (every net traced to a 6-pin contact or named BOM pin) +
    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
    [bom.csv, netlist.csv, vara_cartridge.bom.csv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]
2026-06-03 Phase 5: functional prototype — Pi capture->vision->display+speak pipeline
    app/ with a swappable HAL (real drivers vs clearly-marked stubs, auto-selected + logged):
    - pipeline: jog press -> camera capture -> cloud vision identify -> 240x280 viewfinder+
    caption split -> TTS. No on-device VLM (Phase 1); identify is an Anthropic Claude vision
    call with a cached system prompt.
    - cartridge init enforces the Phase-4 read-before-PWM contract IN CODE: enable_power_pwm()
    raises SequencingError unless read_id() ran first (demo proves the guard fires).
    - graceful degradation: no-wifi / no-key / timeout / API-error each map to a typed
    VisionError -> clean error screen + spoken message -> idle.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
    [audio.py, camera.py, cartridge.py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]
2026-06-03 Phase 6: Three.js exploded showcase — the wrapper
    Static Three.js (no build step), consumes REAL geometry/data only:
    core.glb + cartridge.glb (Phase 3), gen1-6.glb (Phase 2 evolution), Phase-5 frames,
    numbers from dovetail-study. Browser-verified (Playwright): loads, no JS errors, all
    3 scenes render.
    Three scenes:
    - EXPLODE: core<->cartridge separate; 9 tappable callouts give what + WHY (rail span drove
    the form, optical bore coaxial w/ ±0.28mm budget, finger-root fillet functional, ...).
    - CONNECTOR EVOLUTION: step/play G1 (e=13.5%, 1253N, FAIL) -> G6 (SF 5.1, 2.9N/10.6N,
    RESOLVED), real metrics + verdict colors updating live.
    - IDENTIFY: product story + cartridge slide-on + captur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
2026-06-03 Phase 6.5: geometry polish + full-product breakdown
    JOB 1 — visual quality:
    - Re-exported core.glb + cartridge.glb at fine tessellation (tol 0.025, ang 0.07) so the
    barrel/fillets stop faceting.
    - Three.js: toCreasedNormals(34deg) -> smooth curved faces, hard edges stay hard (replaces
    the blanket computeVertexNormals that rounded everything).
    - Matte PA12-CF materials: low metalness, roughness ~0.68, procedural roughness speckle.
    - Lighting: RoomEnvironment IBL (intensity 0.55) + stronger key + rim + fill for crisp edges.
    JOB 2 — full product, honestly:
    - Added representative internal components as their own GLBs (cad/internals/rep_parts.py),
    exploded on the mating axis: Pi Zero 2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
2026-06-03 Phase 6.5b: showcase polish — studio lighting, free camera, clean teardown, fixed assembly
    Addressing review feedback:
    - LIGHTING: gradient backdrop (transparent canvas), studio key(shadow)+rim+fill+IBL,
    PCFSoft contact shadow on a ground plane (fades out as you explode), exposure 1.12.
    - CAMERA: free orbit/pan; fly-to now CANCELS on user interaction (controls 'start') so it
    never fights you; polar clamp; wider zoom range.
    - ASSEMBLY no longer clips through walls: cartridge assembles via hover-align→seat path —
    the WHOLE cart group (shell+optics+EEPROM) lifts 26mm clear, slides into alignment, then
    descends to seat. Verified the lift (cz=26 during slide) via debug trace.
    - FULL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
2026-06-03 Phase 6.6: product-grade detail + render polish
    Detailed, dimensionally-honest showcase geometry (cad/showcase/build_parts.py) realising
    the full intended design — Phase-3 validated STLs untouched:
    - Enclosure split into front housing + back cover, fixed by 4x M2.5 SHCS (exact ISO 4762
    dims), visible/exploding. Glass screen cover, knurled jog wheel, power button, USB-C recess,
    speaker grille, debossed 'VARA' on the cover.
    - Cartridge v2: lens barrel + flange + knurled retaining ring + LED ring.
    - Internals at REAL datasheet dims: Pi Zero 2 W (65x30, 58x23 holes, 40-pin header, SoC,
    WiFi can, connectors), 1.69in display module, Li-po, camera v2, pogo housing+pins.
    - Honesty preserved: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
2026-06-03 Phase 6.7: connector/enclosure correctness + complete electronics
    Fixes the review-flagged flaws, verified geometrically:
    - CONNECTOR no longer goes through walls: the dovetail socket is now an OPEN channel to the
    +X device edge so the cartridge genuinely slides in. VERIFIED cartridge ∩ core = 2.7 mm³
    (just the detent engagement) vs 154 mm³ before — no wall penetration. Identify slide is a
    clean straight slide-in along the open channel (no hover/lift hack).
    - REAL fasteners (not a random screw): 4× M2.5 case screws (cover counterbore → front-housing
    threaded boss) + 4× M2.5 Pi-mount screws into standoffs — every screw in a matching hole.
    - EXACT dimensions: enlarged enclo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
2026-06-03 Phase 6.8: fix floating screw, all-around lighting, view presets
    Review fixes:
    - RANDOM MIDDLE SCREW fixed: the explode loop overwrote each part's seated Z with exZ*t,
    so the Pi-mount screws (seated Z=-9.5) snapped to Z=0 (mid-body) and popped out from the
    centre. Now each explodable stores its base position and the offset is ADDED — screws
    stay in their real holes (case screws at cover corners, Pi screws by the Pi).
    - LIGHTING: was top-only so undersides went black. Added a camera-following headlight (the
    viewed side is always lit) + an under-fill light + brighter hemisphere ambient + higher
    env intensity; softened the key. Widened orbit so the underside is reachable.
    - VIEW PRE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
2026-06-04 Phase 6.9: red-team teardown fixes — screw placement, ordering, separation
    From a close review of the exploded render:
    - Verified all 8 screws render (4 case + 4 Pi) — the earlier 'one screw' was 3 being small/
    occluded. Moved the 4 M2.5 CASE screws into the gap between back cover and front housing
    (exZ 56→14) so they clearly read as the joining fasteners at the 4 corners.
    - Re-ordered the explode to match physical seated-Z so parts don't cross: the CAMERA was
    flying into the middle of the green-PCB cluster (exZ -52); moved it next to the housing
    (-12) where it sits by the bore. Pi/carrier deepened; battery separated (exZ -14→-24)
    so it clearly leaves the housing; pogo abov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
2026-06-04 Phase 6.10: final teardown red-team — caching, clean cartridge seat, screws
    Root cause of 'still not fixed' was CACHING: ES module imports weren't cache-busted, so the
    browser served stale main.js/GLBs (the review images showed the pre-6.9 layout). Added a
    no-cache static server (web/serve.py) so edits are always seen on refresh.
    Geometry/render fixes verified fresh (Playwright + interference check):
    - Cartridge no longer shows exposed orange rail tabs: CLOSED the dovetail socket so the cover
    fully wraps the rails (the open channel was exposing them from the side). Cartridge gets a
    proper overhanging FLANGE; it now seats as a clean lens module. Interference still 2.7 mm³.
    - Identify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
2026-06-04 Phase 7: README, BUILDLOG, future-cartridges, deploy guide, hero render
    - README.md: engineer's-eye story — honest framing first (one engineering pass, validated-by-
    design not hardware-tested, Pi is real / electronics are a documented design), the dovetail
    G1→G6 narrative, camera-to-core decision, read-before-PWM guard, KiCad ceiling, and an
    explicit DESIGNED-vs-REPRESENTATIVE table. Hero render at docs/img/hero.jpg.
    - BUILDLOG.md: phase-by-phase decision record (probes, dead ends, honesty calls) — auditable.
    - docs/future-cartridges.md: thermal/air-quality/audio as architecture-only; proves the 6-pin
    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
2026-06-04 Phase 7: dual license (MIT software + CERN-OHL-S v2 hardware)
    Per decision: MIT for software/docs (app/, web/, scripts, docs), CERN-OHL-S v2 (strongly
    reciprocal) for hardware design (cad/, electronics/). LICENSE explains the split + tradeoff;
    LICENSE-MIT + official LICENSE-CERN-OHL-S-2.0.txt (verbatim from SPDX). Honesty note: licenses
    cover design files; validated-by-design, not hardware-tested.
2026-06-04 Add standalone animated assembly page (model-viewer, not three.js)
    New separate page web/assembly/ showing the whole CAD assembling from exploded → seated on a
    loop, with a turntable. Built as a single animated glTF (cad/showcase/build_assembly_gltf.py):
    trimesh reads the 26 showcase part GLBs, pygltflib authors one scene with per-node translation
    animation + baked PBR materials + the Z-up→Y-up parent rotation. Played in Google
    <model-viewer> (CDN-pinned 4.0.0) — autoplay + auto-rotate + orbit/zoom; deliberately simpler
    and passive vs the interactive three.js showcase. Links back to it. Honesty footer kept.
    Browser-verified: 0 errors; parts fly apart and reassemble; clean seated state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
2026-06-04 Polish the assembly page to product-render quality
    - Studio HDR IBL (env.hdr, polyhaven studio_small_03 1k) — the big lift: realistic material
    response + reflections, replacing model-viewer's flat default lighting.
    - Material upgrade: clearcoat sheen on glass/screen/cartridge/rings, true metals (steel screws,
    gold pogo, anodized wheel/rings at low roughness), emissive amber LED ring (ring-light glow),
    warm 'stone' enclosure tuned for the bright HDR.
    - ACES tone-mapping, exposure 0.9, stronger soft contact shadow (intensity 1.5).
    Result reads as a clean studio product render — matches/exceeds the three.js scene.
    Browser-verified: 0 errors; assemble→seat loop + turntable; metals/cl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
2026-06-04 Assembly render: bake creased normals (the missing three.js-quality piece)
    The render looked crude because the glTF used trimesh's AREA-AVERAGED vertex normals, which
    round-shade every edge (box corners look soft/melted). Ported the three.js toCreasedNormals
    approach into the builder: angle-based (35°) creased normals so curved faces shade smooth and
    hard edges stay crisp — then re-weld identical (pos,normal) pairs so size stays sane
    (7.9 MB → 2.65 MB, no quality loss). Now reads as a crisp product-CAD render to match/beat the
    interactive scene. Browser-verified: 0 errors; crisp edges + smooth fillets from all angles.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
2026-06-04 README: embed the animated assembly GIF + exploded teardown still
    Add a "See it move" section up top — the looping exploded→seated animation
    (captured from the model-viewer page) and a clean exploded-teardown still,
    both rendered straight from the Phase-6 CAD.
2026-06-04 README: annotated teardown, capabilities/roadmap, trim internal scaffolding
    - Swap the clean exploded still for the annotated teardown from the three.js
    showcase — every part with a leader label + DESIGNED/REP badge.
    - Add "What it can do — and where it can go": the platform/contract framing,
    what works today, designed-in cartridge extensibility, and a concrete (honest,
    unbuilt) roadmap — keeping the validated-by-design spine.
    - Remove VARA_BUILD_PLAN.md (internal planning scaffold) and the empty anim/
    placeholder; reword the four docs that cited the plan so nothing dangles.
